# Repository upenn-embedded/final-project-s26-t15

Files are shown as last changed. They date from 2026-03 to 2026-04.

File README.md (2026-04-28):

Review Assignment Due Date (https://classroom.github.com/a/-Acvnhrq)

# Final Project

**Team Number: Team 15**

**Team Name: Argus**

| Team Member Name | Email Address |
| --- | --- |
| Seth Lee | sethlee@seas.upenn.edu |
| Jerry Zhang | jerryjz@seas.upenn.edu |
| Thomas Liu | tholiu@seas.upenn.edu  |

**GitHub Repository URL: https://github.com/upenn-embedded/final-project-s26-t15.git**

**GitHub Pages Website URL:** https://upenn-embedded.github.io/final-project-s26-t15

## Final Project Proposal

### 1. Abstract

Our final project (Argus) is a pair of augmented reality glasses that utilizes a HUD and sensor suite to collect and display movement information along with live timers that always keep the user up to date with their activities. Using a STM32 MCU and XIAO ESP32S3 processors, we can wirelessly transmit data from the glasses to our pocket. Featuring a transparent OLED for the HUD, 9-axis IMU for spatial tracking, and capacitive touch sensors, we combine portability with performance. The ESP32s will relay data wirelessly from the glasses to the STM32 in the user's pocket which serves as the compute hub.

### 2. Motivation

Argus helps bridge the gap between physical activity and real-time data accessibility without sacrificing situational awareness. While commercial AR glasses often prioritize complex media ecosystems and overlays, Argus focuses on lightweight, purpose-focused architecture that offloads heavy processing to a pocket-based STM32 to minimize weight. The sensors then provide a distraction-free, hands-free HUD for users. Instead of having to look at a watch or pull out a phone, users can find relevant telemetry in their line of sight. The emphasis on power efficiency and simplicity makes it perfect for tasks like checking the direction of travel while running or biking, where looking down could be unsafe. We hope that this project can provide a base for more advanced sensors and features.

### 3. System Block Diagram

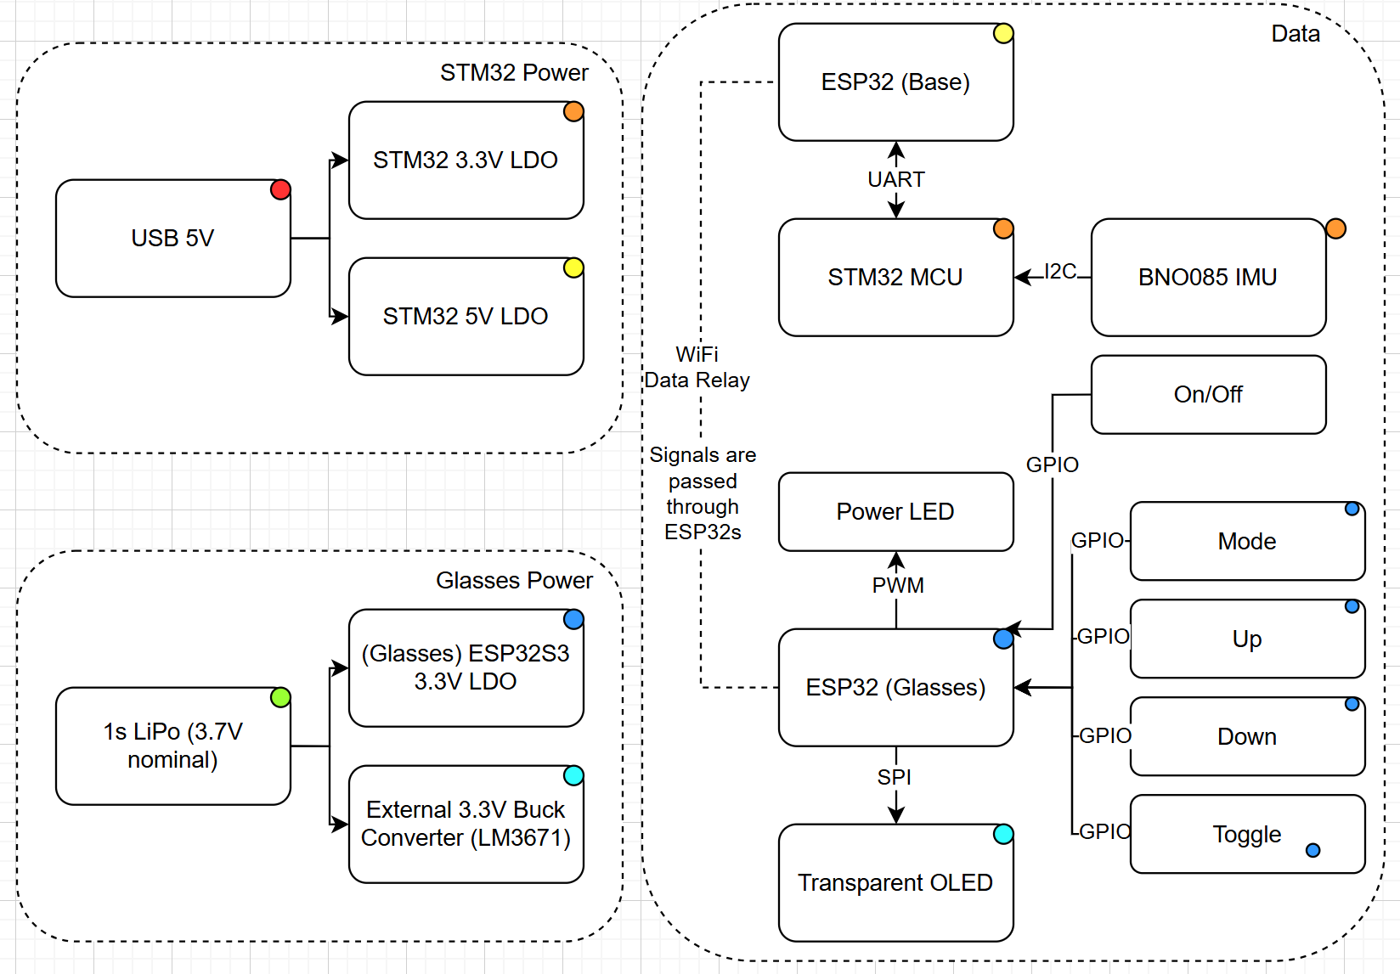
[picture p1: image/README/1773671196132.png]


### 4. Design Sketches

The frame of the glasses will be customized through 3D printing and laser cutting in order to house the hardware components.

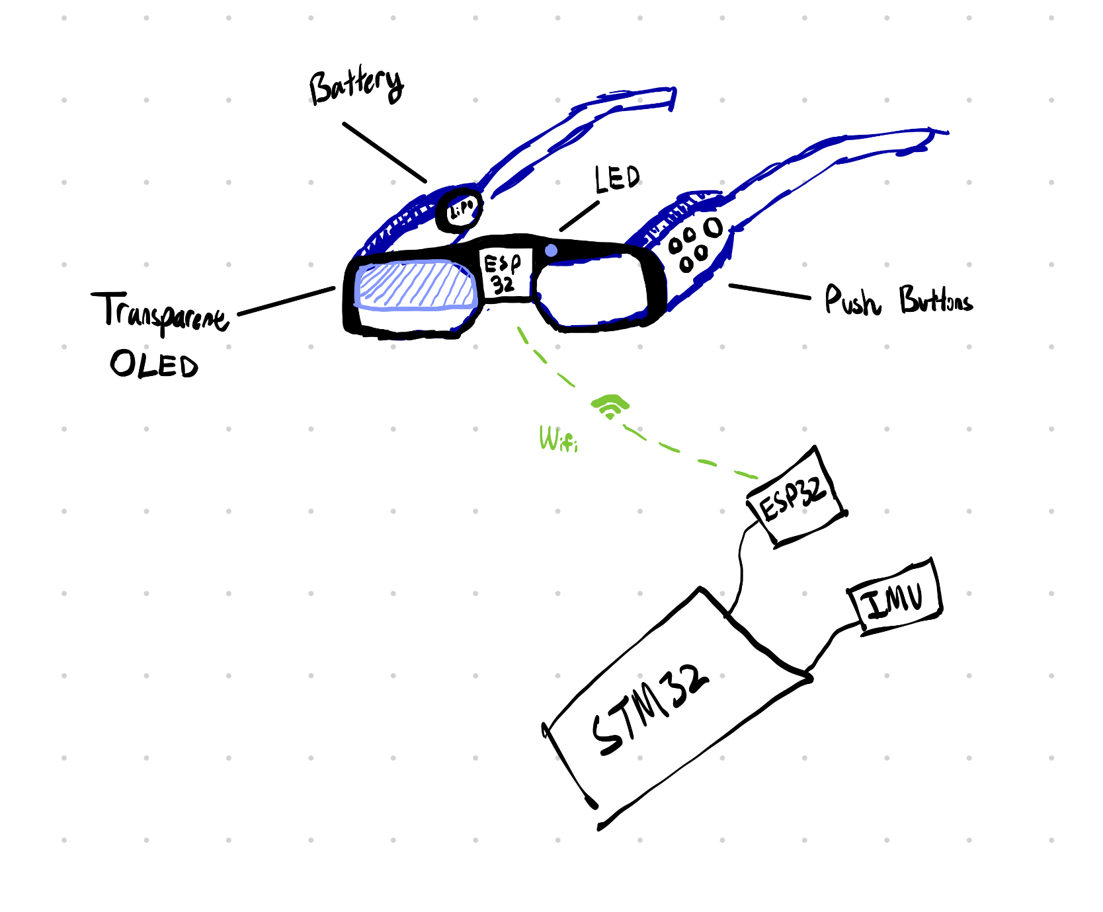
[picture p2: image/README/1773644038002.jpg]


### 5. Software Requirements Specification (SRS)

**5.1 Definitions, Abbreviations**

STM32 - STM32F411RE microcontroller on the NUCLEO-F411RE development board.

Base ESP32 - the ESP32 module connected to the STM32 via UART.

Glasses ESP32 - The ESP32 module mounted on the glasses frame. Receives data from the Base ESP32 and interacts with peripherals.

IMU - Inertial Measurement Unit. Accelerator/gyroscope sensor for step detection.

**5.2 Functionality**

| ID | Description |
| --- | --- |
| SRS-01 | The STM32 shall read the IMU accelerometer data over SPI at a minimum rate of 50 Hz to enable accurate step detection. |
| SRS-02 | The step detection algorithm shall detect a walking step within 400ms of it occuring, with no more than 10% error over a 20-step walk test. |
| SRS-03 | The display shall update its shown content within 500ms of a button press. This includes the full round-trip: glasses ESP32 → base ESP32 → STM32 → base ESP32 → glasses ESP32 → display. |
| SRS-04 | The STM32 shall synchronize its RTC with NTP time via the base ESP32 over UART once at startup. |
| SRS-05 | The display shall cycle through atleast three different modes, such as: time view, step count view, and compass view. |
| SRS-06 | The STM32 shall receive and process data from the base ESP32 over UART within 100ms of transmission. |
| SRS-07 | The STM32 shall compute the compass direction from the magnetometer data from the IMU and display cardinal direction (N, NE, E, SE, S, SW, W, NW) accurate to within +/- 22.5 degrees after calibration. |
| SRS-08 | The OLED display will communicate using SPI translated through UART wirelessly between the two ESP32S3 modules to maximize screen data bandwidth. |

### 6. Hardware Requirements Specification (HRS)

**6.1 Definitions, Abbreviations**

See Section 5.1 for all definitions and abbreviations.

**6.2 Functionality**

| ID | Description |
| --- | --- |
| HRS-01 | The system shall use an IMU with atleast 3-axis accelerometer, 3-axis gyroscope, and 3-axis magnetometer capabilities, communicating over SPI, to provide motion data for step-count and compass data for direction. |
| HRS-02 | The display shall be smaller enough to mount on glasses frames and support atleast two lines of text output. |
| HRS-03 | Several push buttons shall be mounted on the glasses frame and be able to register a press within 100ms of acutuation to enable various functionalities such as toggling modes, changing parameters, and powering on and off. |
| HRS-04 | Two ESP32 modules shall be able to maintain wireless connection with a round-trip latency of less than 500ms within 5m of distance. |
| HRS-05 | The STM32 shall communicate with the base ESP32 over UART at a baud rate of atleast 9600 bps. |
| HRS-06 | The glasses shall be powered by a battery capable of powering the glasses for atleast 15-30 minutes continuously. |

### 7. Bill of Materials (BOM)

The major components needed are as follows: Nucleo STM32 F411RE Devboard, 2x XIAO ESP32S3 modules (wifi communication), DFR0934 monochrome transparent OLED (HUD), 9-DOF IMU (motion tracking), a LED to indicate power and debug features, external buck converter to isolate OLED from possibly noisy ESP32 LDO, 5 switches (mode, up, down, toggle, on/off), and a battery.

| Component | Part Selection | Justification & Requirement Link |
| --- | --- | --- |
| Main Processor | NUCLEO-F411RE | Master Controller: Handles the step-detection algorithm (SRS-02), RTC synchronization (SRS-04), and I2C sensor polling at 50 Hz (SRS-01). Selected for its ability to use interrupts and also industry standard usage. |
| Wireless Bridge  | 2x XIAO ESP32S3 | Communication Relay: Facilitates the 500ms round-trip display update (SRS-03) and provides the wireless link required by HRS-04. Operates as a simple relay with no application code to satisfy system constraints. |
| Transparent HUD  | DFR0934 OLED | Visual Interface: Meets HRS-02 for small-form-factor mounting and supports the multi-mode display requirements (Time, Steps, Compass) outlined in SRS-05. |
| Motion Tracking  | 9-DOF IMU (BNO085)  | Navigation & Fitness: Provides the 3-axis Accel/Gyro/Mag data required by HRS-01. Enables compass accuracy within 22.5 degrees (SRS-07) and step detection (SRS-02). |
| Power Isolation  | Buck Converter | System Stability: Ensures that WiFi bursts do not cause brownouts or electrical issues, allowing the battery to meet the 15 to 30 minute continuous run-time requirement (HRS-06). |
| User Input | 5x Tactile Switches | Manual Control: Satisfies HRS-03 for registration within 100ms. Enables mode toggling (SRS-05) and system power management. |
| Power Source | 1S LiPo Battery | Portable Battery: Selected to meet the weight requirements for glasses-mounting while satisfying the run-time specifications of HRS-06. |
| Status Indicator | Power LED | Visual Feedback: Provides an immediate hardware-level On state to confirm the success of power-on sequences defined in HRS-03. |

https://docs.google.com/spreadsheets/d/1X19fjBgSUE6MPIu0bsC3vZN--DqyP1meB3pUoyBd7XM/edit?usp=sharing

### 8. Final Demo Goals

On Demo day, the smart glasses will be demonstrated by having someone wear them. The STM32 with its base ESP32 will have remain close by when the user is using the smart glasses to reduce latency and improve connectivity between the two ESP32 modules. Features will be tested by activating them using the side push buttons and moving around which will verify functionality of IMU features (cardinal direction and step counting) and the screen updating.

### 9. Sprint Planning

| Milestone  | Functionality Achieved | Distribution of Work |
| --- | --- | --- |
| Sprint #1  | 1] Get individual components to connect to each other, i.e STM32 and ESP32.<br />2] Verify UART connection between STM32 and ESP32, wifi-connection, and confirm that STM32 can recieve button press.<br />3] Begin prototyping glasses frame + begin calibrating screen for close-up view.<br />4] synchronize RTC time with NTP time via wifi. | Seth - Firmware<br />Jerry - Display + Firmware<br />Thomas - Glasses Frame |
| Sprint #2  | 1] Get STM32 to receive IMU data over I2C and display steps / compass direction<br />2] Get display to show text/time.<br />3] Finalize power source for the glasses display + ESP32.<br />4] Finalize Glasses Frame and test it for proper fitting/balance. | Seth - Firmware<br />Jerry - Display + Peripheral Integration<br />Thomas - Glasses Frame  |
| MVP Demo | 1] Get steps algorithm and compass direction working.<br />2] Fully integrate ESP32 and display onto glasses frame.<br />3] Ensure that calibration + synchronizing of RTC time work as expected. | Seth - Firmware<br />Jerry - Peripheral Integration + Calibration<br />Thomas - Integration |
| Final Demo | Ensure that final product is fully functional and meets requirements. | |

**This is the end of the Project Proposal section. The remaining sections will be filled out based on the milestone schedule.**

## Sprint Review #1

### Last week's progress

1. Finalized most of BOM and determined general design of prototype that we are now working towards.
2. Ordered parts for parts of the deisgn that we are more certain on
3. Planning design and build schedule.

### Current state of project

1. Found several issues with current design mostly surrounding difficulty of writing I2C driver with our IMU.

-> Strange behavior listed in errata of F411 where clock stretching results in miscommunication between master and slave, which is problematic since the previous IMUs chosen (BNO085 or BNO055) both use it. Also discovered these devices don't contain built in step counter and I2C will be very difficult to write.

-> Switched to LSM6DS0 because it contains step counter and works over SPI. Since screen also uses SPI, it makes it convenient so we can write one driver that is also easier to write.

2. Button presses and interacting with the STM32F411 figured out

-> Basic interrupt or GPIO functionality

3. Replaced the transparent OLED with a DFR0934 along with a different design (described below) for handling the optics. This was done because the the transparent OLED would not be visible at such a close distance.
4. Calculated object distance (d0) constraints from a target virtual image distance (d1) and magnifcation (m0) constraint.

[d0 calculator (32)](https://www.desmos.com/calculator/zhws0yhlh0)

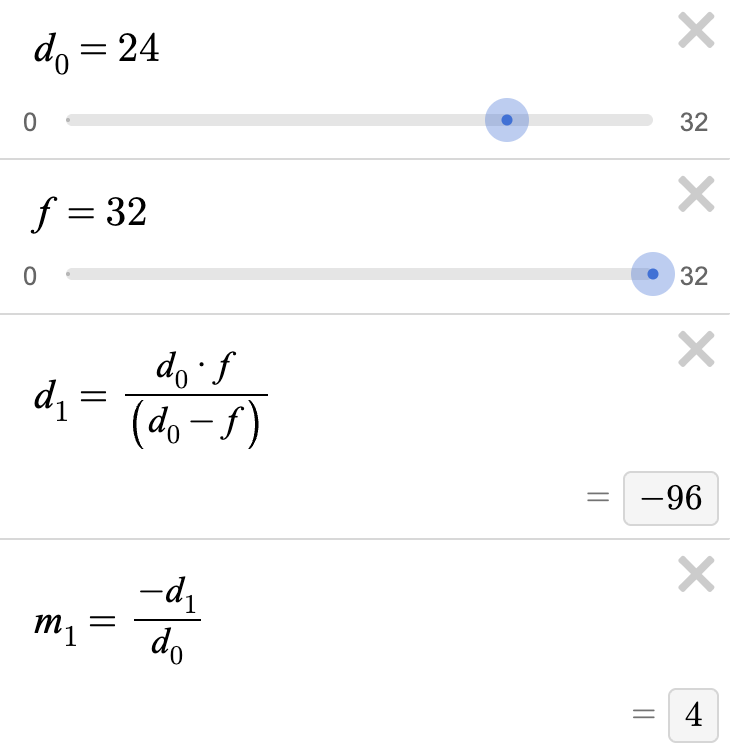
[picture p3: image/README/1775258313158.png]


4. Designed the mechanical layout for the hardware and optics Determined methods to reduce d0 due to limited focal length, and reduce mount size by adding a secondary mirror.

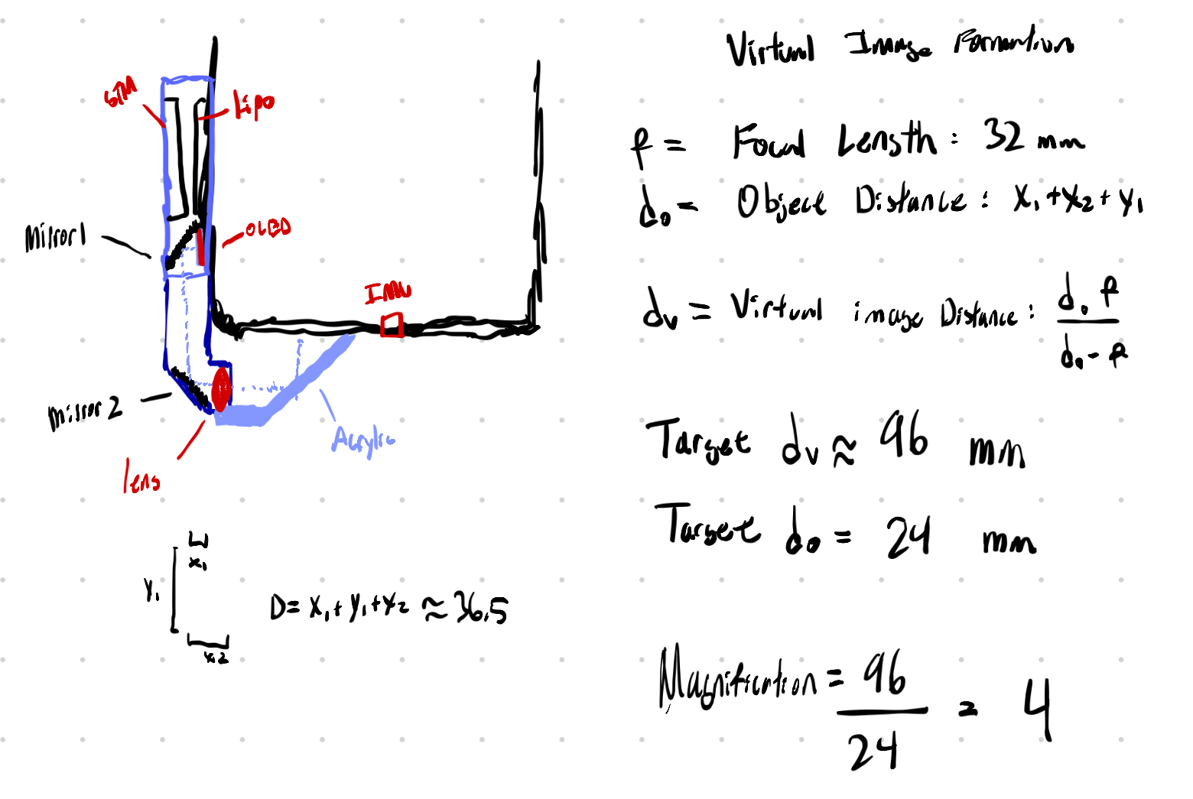
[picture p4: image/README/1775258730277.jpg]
   
5. Prototyped mounts to hold hardware so they can be clipped onto glasses.

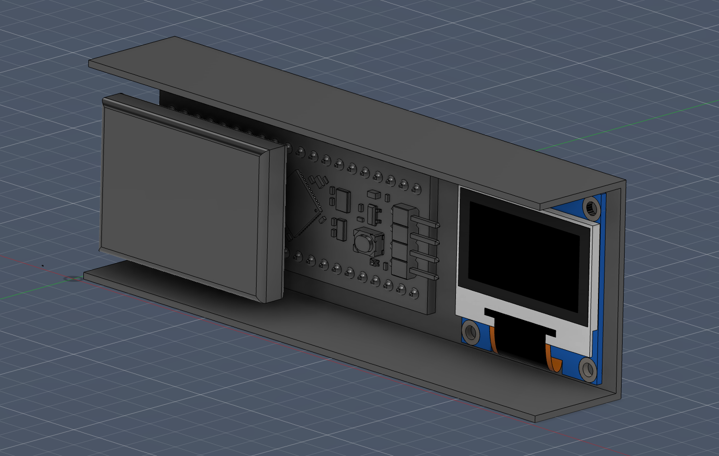
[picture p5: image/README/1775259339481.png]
   

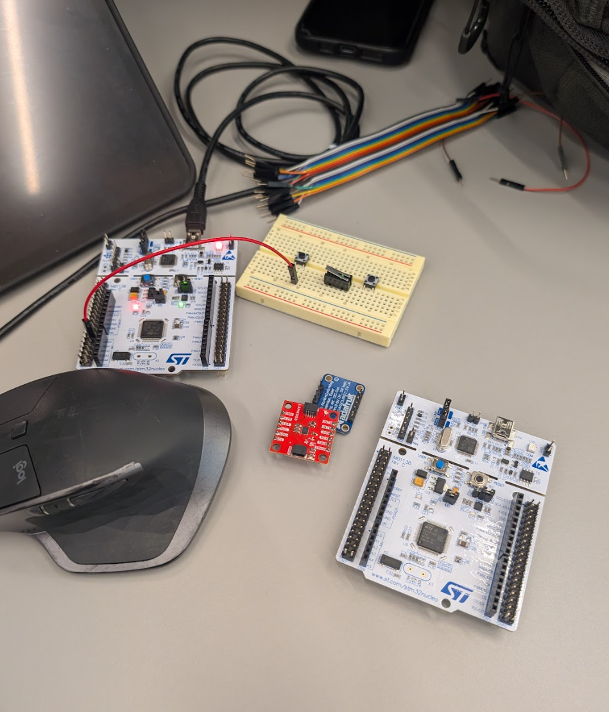
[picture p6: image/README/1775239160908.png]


### Next week's plan

1. Finish full implementation of step counter (Seth)

-> Requires full functionality of SPI drivers

-> Get it to read out onto a serial output

-> Est. time: 1hr if SPI driver is working

2. (If screen arrives) Write library and implement basic functionality of screen (Jerry)

-> Allow for some basic interfacing with screen, determine how to set the screen color or edit pixels

-> Est. time: 2-3hrs

3. Write SPI driver (Jerry)

-> SPI driver has all necessary features for at least the IMU at this time, can initialize and operate independently without excessive debugging or compatibility issues with devices

-> Est. time: 3-6hrs

4. Write IMU driver (Seth)

-> Implement all major functions (get linear movement, step tracking, etc)

-> Est. time: 3-6hrs

5. CAD and print out a prototype (Thomas)

-> 3D-print a prototype (or gather a pair of real glass) and mount a dummy weight mimicking our device onto glasses and test weight distribution.

-> Est. time: 3-6hrs

Hopefully we also get some parts in.
Work Distribution:
Seth: Firmware and development of STM32 portions
Jerry: Electrical hardware and writing SPI driver
Thomas: Mechanical design and prototyping

In case anyone is not available to work on something, everyone is reading the STM32 textbook and is proficient in mechanical design so we can assist each other if extra work is needed.

## April 9th, 2026

As of now, the main SPI driver is written and the IMU driver is in progress. Using the textbook as a reference, we're trying to write the driver for the LSM6DS0 so that it can use SPI properly. The mechanical design is nearly done (insert screenshot). We are also able to register basic GPIO input and some input capture using buttons so far on the STM32.

## Sprint Review #2

### Last week's hardware progress

This week, we targeted integrating various sensors and drivers, making sure that our devices are taking and outputting the proper data. Additionally, we hoped to get some of the new parts (OLED, lenses, Adafruit Blackpill STM32) so that we could move to our intended hardware setup. While the lenses and Blackpill STM32 have not arrived, the OLED has arrived.

After analyzing the hardware components' sizes and the constrains on the optical components, new designs analyzed. The final design for prototyping will resemble design one, but with the hardware shifted to account for proper lens spacing. Later, prototypes will look like design three if space is too constrained.

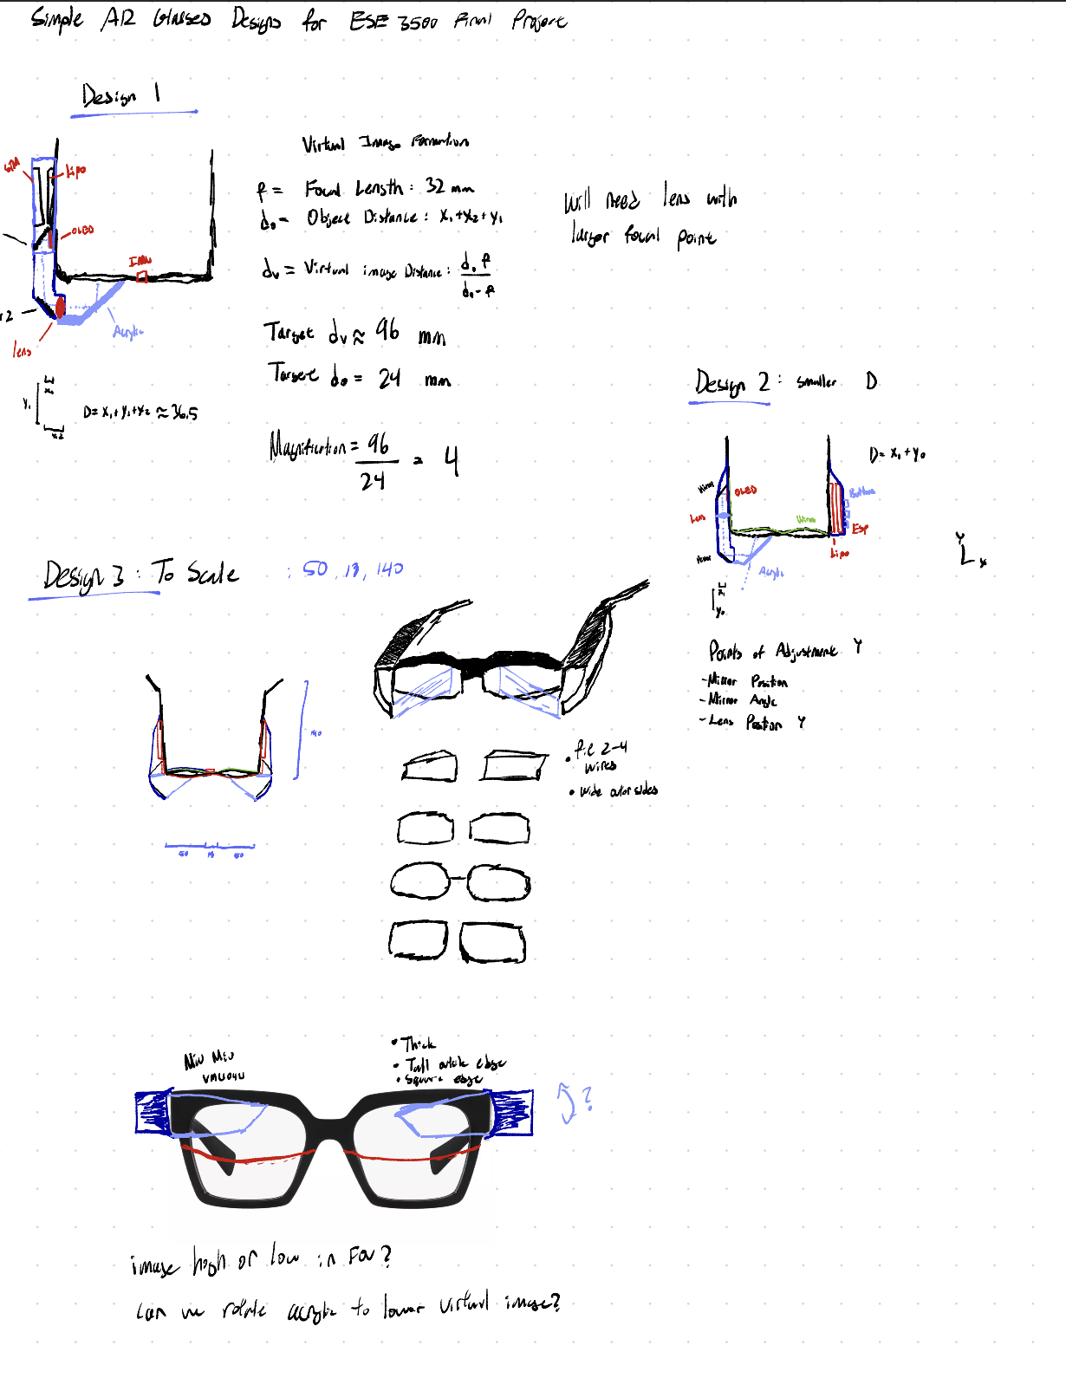
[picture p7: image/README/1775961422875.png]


To attempt to reduce the total thickness of the mounts, the furthest distance between the mirror and the OLED was minimized. Onshape was used to simulate raytracing by creating variables and minimizing the base length through different configurations.
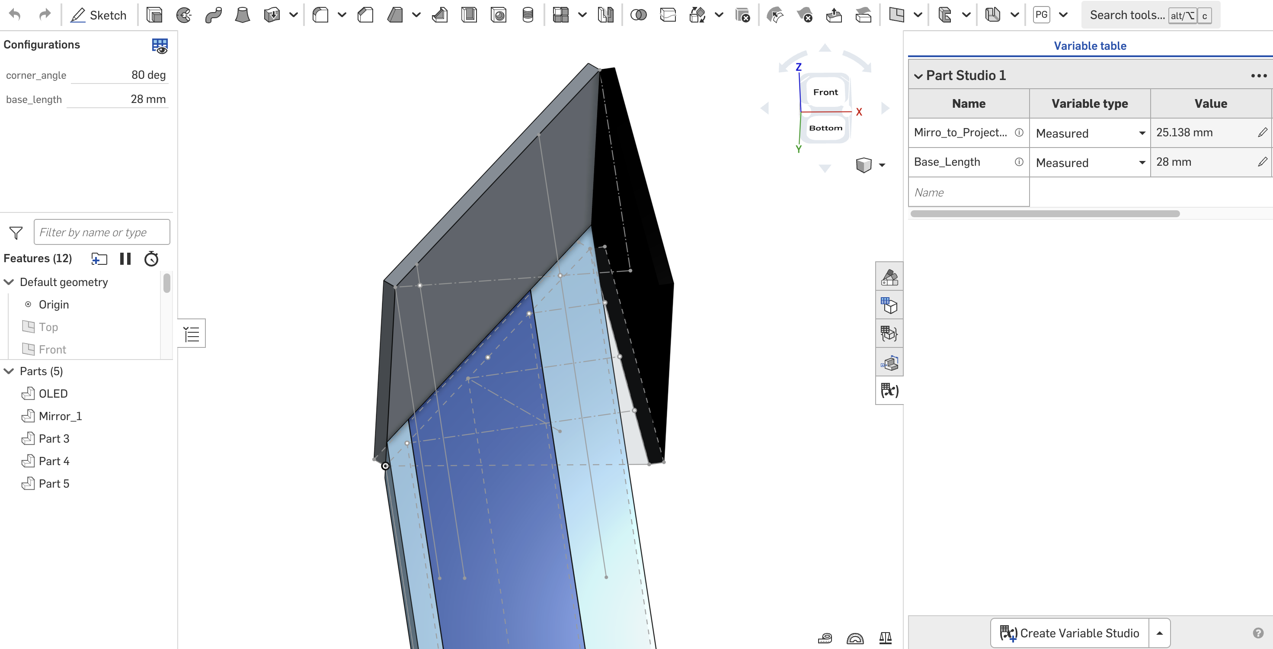
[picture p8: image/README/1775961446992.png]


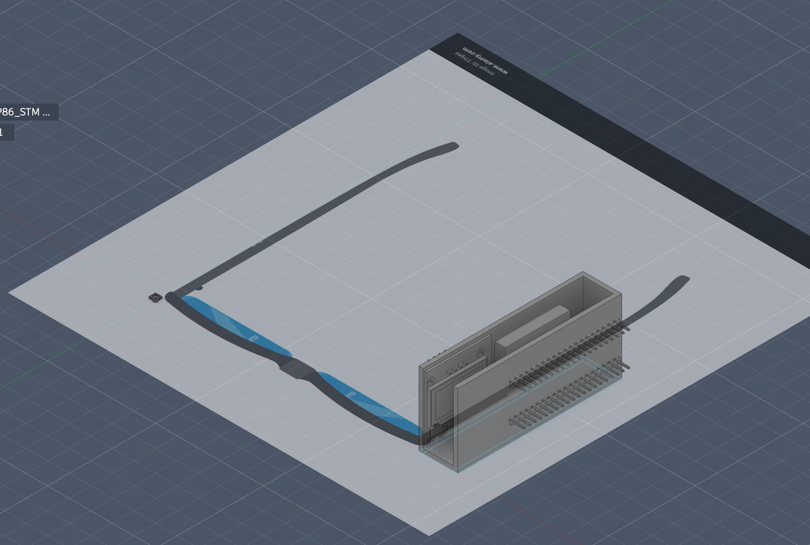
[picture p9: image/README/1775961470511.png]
Once the hardware arrived, components were measured with calipers to verify their measurements. A pair or glasses was also measured as a reference. Then, a canvas scaled to the glasses' size was imported into Fusion 360, where components were resized and the mount was scaled. Printing is underway to enable testing of the optics once the mirrors and lens arrives.

### Last week's electrical progress

Last week, we made some important progress on the integration of sensors and development of the blueprint of the device. Using the basic plan we had devised last week to primarily work on device drivers, communication protocols, and developing the optical system, we have reached a position where we are satisfied with current progress and are on track to create a MVP.

The table below reiterates some of our barebones MVP guidelines:

| MVP Goal | Description | Status |
| --- | --- | --- |
| #1. IMU Step Counter | The smartglasses will contain basic motion tracking capabilities, using an IMU to track the wearer's steps. | Complete. The SPI and IMU drivers have been fully written for the LSM6DS0, but there are other issues (written below). |
| #2. On-Screen Timer System | A wearer will be able to set and be notified of timers for use such as in timing activities like cooking or taking a practice exam. | Incomplete. The timer system will be created through the use of hardware timers, the software has not been written yet. |
| #3. 2-4 Buttons for Screen Control | The smartglasses will have several buttons to interface with the GUI to interact with features such as the step counter, timer system, or compass. | Incomplete. Basic GPIO features have been tested, but software must be written. This will be complete after all other subsystems are operable. |
| #4. Optical Waveguide HUD | The smartglasses will contain an optical waveguide to translate the light of the OLED to a beamsplitter which will reflect the light into the wearer's eyes, giving the illusion of a "floating" HUD in their vision. | In Progress. The OLED has arrived and its drivers are currently being developed. The calculations for the lens size and mirrors have also been completed. |
| #5. CAD of Glasses or Waveguide Holder | The smartglasses will exist in the form of either a clip-on attachment to an existing pair of glasses or as a standalone frame. | In Progress. The CAD has partially been completed with some additional testing and printing of the parts needed. Additionally, not all of the optical hardware (mirrors) has arrived yet. |
| #6. Navigation System | The smartglasses will contain a basic navigation system consisting of a cardinal compass to allow the user to receive navigation data. This may extend outwards into the usage of GPS or other features. | The initial IMU used (LSM6DS0) does not contain the magnetometer required for the compass. A version with the magnetometer has been ordered. |

### Current state of project

To summarize, we have written drivers and tested functionality for the IMU step counter subsystem. The video below shows (poorly) the operation of the step counter:

https://drive.google.com/file/d/1mDCpxerKAkAiZ3uGaSlx3KKA8HsJcfL3/view?usp=sharing

This link will be updated to a YT video in the future.

We found that the step counter works well, although there is a delay in counting steps. This is by design as to avoid overcounting steps as a result of other oscillatory motion.

The SPI and IMU drivers were also written, taking about the expected amount of time as listed in Sprint Review #1. Unforunately, the OLED did not arrive until recently, so that was not able to be tested yet. However, the driver for that is in progress. Since it also uses SPI, we expect setup to be easier along with our past lab experience in writing a portion of a screen driver.

Here is the step counter:

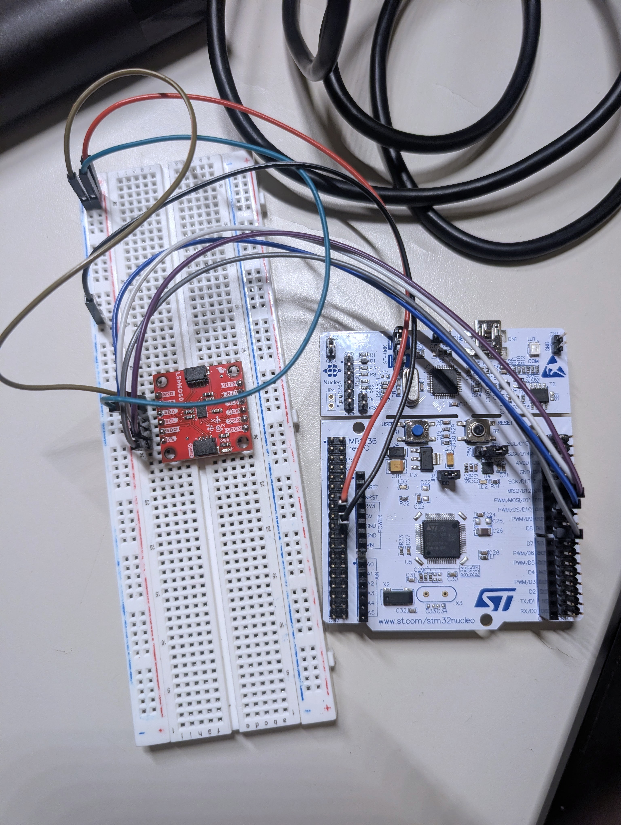
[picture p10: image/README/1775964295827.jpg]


This image shows some of our commits since the last sprint review.

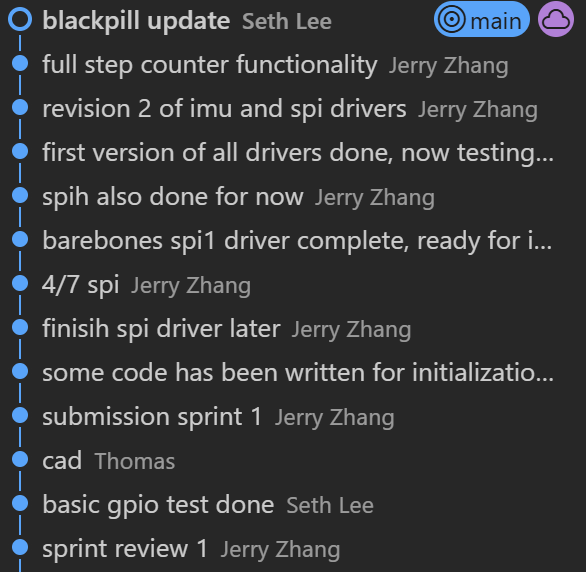
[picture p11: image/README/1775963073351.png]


Unfortunately, we reailzed that the existing parts list was inaccurate and we were unable to find certain parts, forcing us to place some orders later than we wanted to. For one, we wanted to use a 9-DOF IMU so that we could also take advantage of the magnetometer to create a compass. However, Detkin does not stock any dedicated magnetometers and their supply of IMUs is inaccurate to their parts list, only having the LSM6DS0 and some other IMUs which did not have features which we required. This led us to order the Adafruit LSM9DS1, which is effectively the same IMU (saves us time writing the driver) with a magnetometer.

The initial lens choice also proved more difficult to work with than initially thought. Due to the short focal length of the lens (32mm), we found it difficult to place all of our components within that space. However, we found a workaround where we were able to place the lens closer to mitigate this issue.

The battery has also arrived and we are considering using power management to properly adjust the 3.0 - 4.2V LiPo to the proper operating voltages so that we can use it for the entirety of its battery voltage range.

### Next week's plan

The table below illustrates our plans for the following week. To summarize, we hope to test functionality of the OLED, develop a functional CAD and 3d-printed MVP of the device, and develop the UI and user optical system.

| Goal | Owner  | Est. Time |
| --- | --- | --- |
| Develop OLED drivers, write screen functions | Seth | 4-6 Hrs |
| Implement components of UI and improve upon IMU functionality by adding compass and optimizing step counter | Jerry  | 3-4 Hrs |
| Finish CAD and optical system design | Thomas | 3-4 Hrs |
| Update SPI drivers to account for OLED | Jerry  | 1 Hr |
| Write software to handle display switching and update main loop | Seth | 2-3 Hrs |
| 3D print CAD designs and build first MVP (if parts all arrive) | Thomas | 2-3 Hrs |

In general, the goal is to prepare for the MVP demo and to develop a usable hardware system that is modular and lightweight. The OLED drivers will be written and some basic functionality involving GPIO and switching screens should also be implemented as well.

We are well on track and keeping each other up to date with progress.

## MVP Demo

**Refined System Diagram (MVP Demo & Final Diagram):**

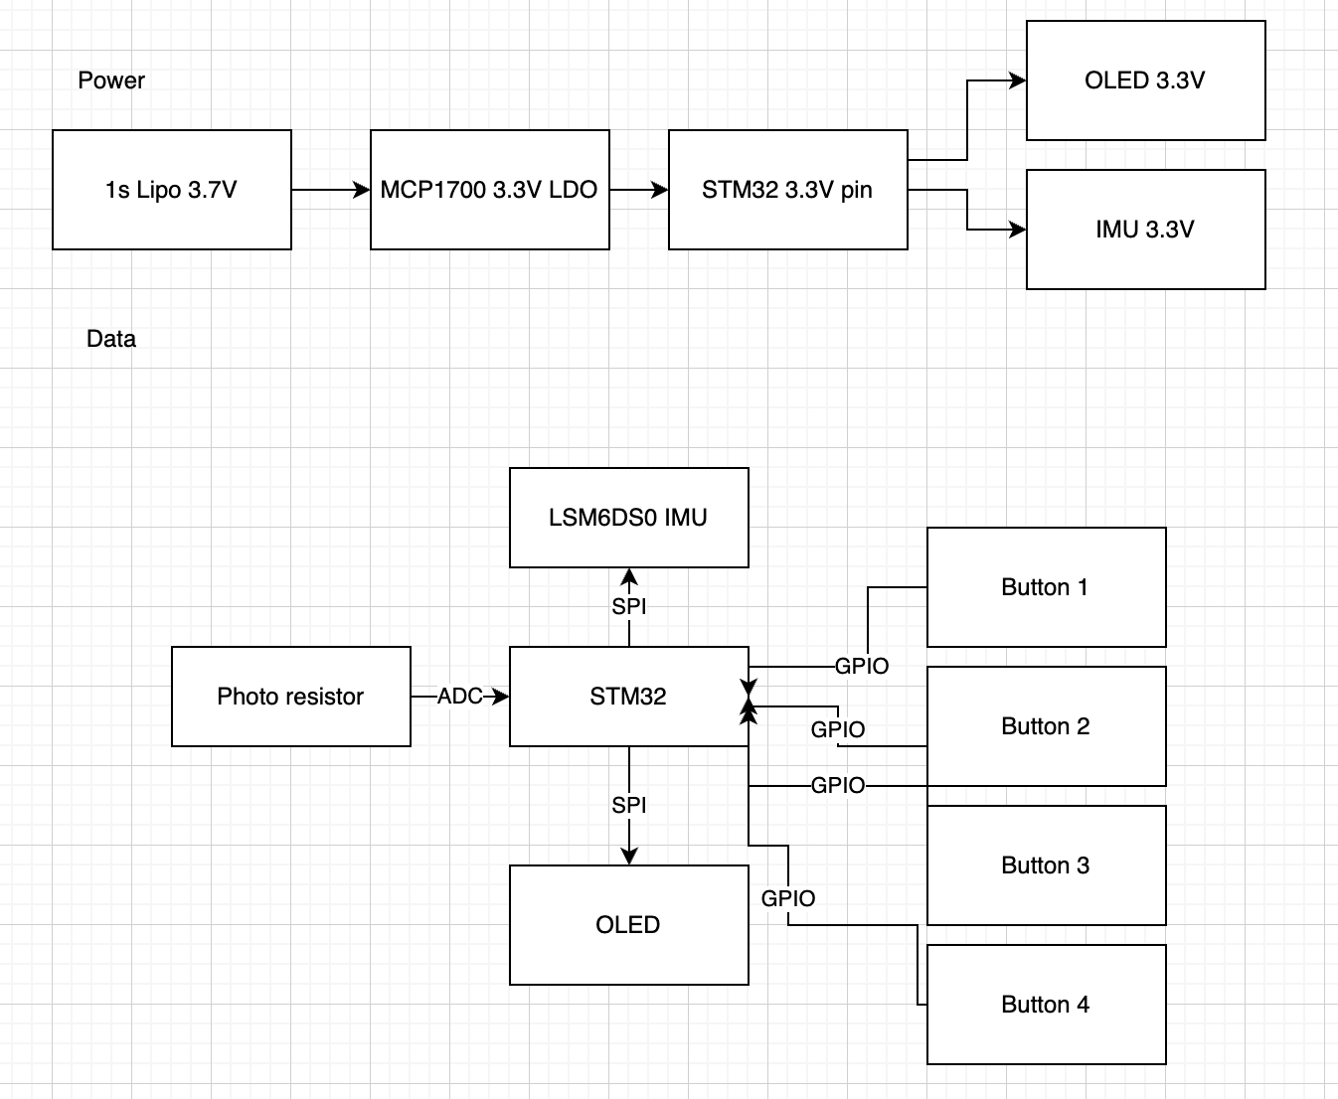
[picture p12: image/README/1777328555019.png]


Note: this diagram only shows 4 buttons instead of 5 since the fifth button on the final product was used to replace a non-functional button due to one of the GPIO pins breaking.

**Firmware Impementation:**

The main firmware is in the main.c file, which calls functions from every other .c file, including the oled.c, spi.c, imu.c, files. The main.c file is where the state of the screen is handled and where all the initialize functions are called. Then, in oled.c, spi.c, and imu.c (which are our drivers), we have the actual function code that instantiates SPI, which is used for both the OLED screen and IMU.

More specifically:

In spi.c: we have two independent SPI buses that run. One SPI bus is for the OLED screen and the other one is for the IMU.

In imu.c: we have functions that read the register from the IMU that stores the number of steps taken. This file also handles interrupts that come from the IMU, which refresh the OLED screen to display the updated step count.

In oled.c: This is the main driver for our SSD1308 oled screen. This has functions for OLED brightness, resetting the OLED screen, and drawing pixels on the OLED screen.

In font.c: This file has various draw functions that use the draw_pixel function from oled.c.

Below is an Image of the working OLED. The text on the OLED will eventually be cast to the front of the lens on the AR glasses.

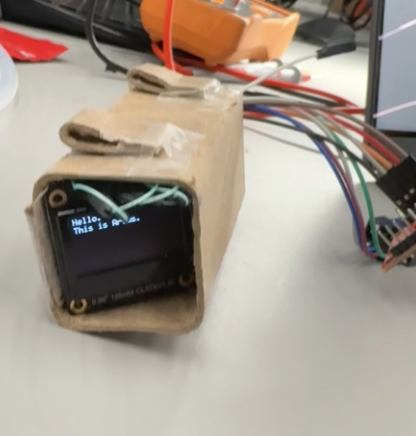
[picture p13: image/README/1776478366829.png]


**Software Impementation:**

We have achieved some of our Software Requirements. Specifically, we have satisfied SRS-01, which is to read the IMU accelerometer data for accurate step detection. Originally, we wanted to have this refresh at 50 Hz. However, this was not possible due to the slow nature of the IMU register updating. However, this is not a big deal since we’re still accurately getting step count.

We also have satisfied SRS-02 (accurate step-count).

We decided to not use the ESP-32 due to extra unnecessary complexity. Therefore, SRS-03 and SRS-04 and SRS-06 are no longer relevant.

SRS-05 is partially completed since we have the basic functionality of cycling between various screens. However, we do not have the magnetometer setup yet (SRS-07), so we are still working on that.

For SRS-08, the OLED works through SPI. However, we decided not to use the ESP32 so the ESP32 part of the requirement is irrelevant. The OLED is fully functional, however.

Below is a picture of the IMU setup.

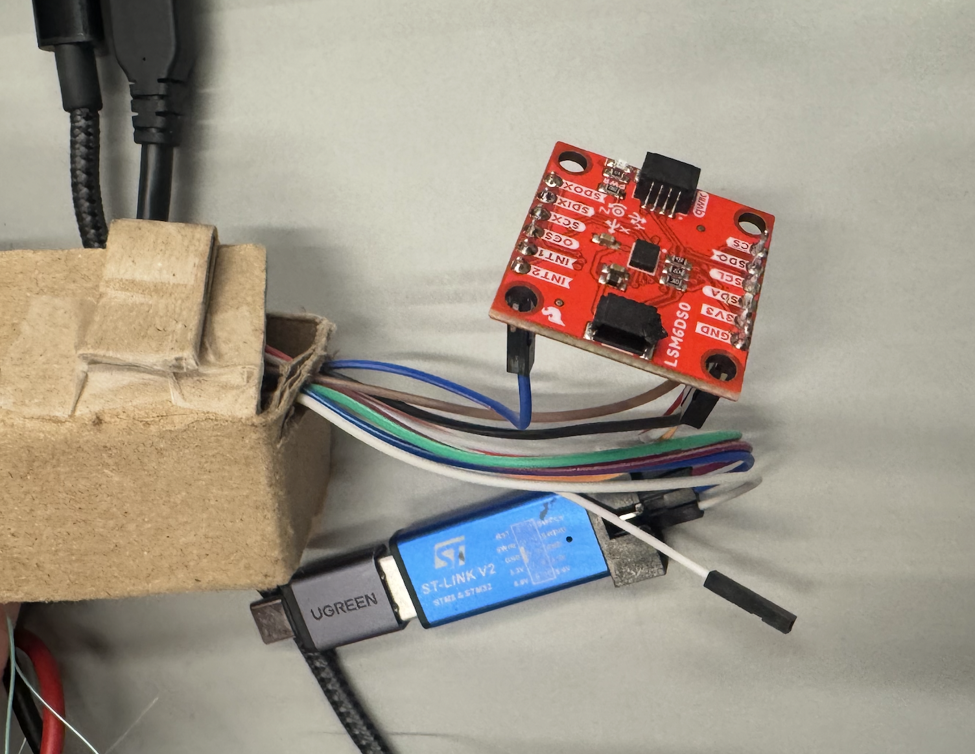
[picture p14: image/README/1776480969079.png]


**Hardware Implementation:**

For HRS-01: we are partially done with this hardware requirement except we currently are using a 6-axis accelerometer because the 9-axis accelerometer we bought requires using I2C, which we do not have setup yet.

For HRS-02: we have satisfied this since our OLED fits on the glasses frame extension and also can display more than 2 lines of text.

For HRS-03: several push buttons register within 100ms and do various functions, such as changing what is on the OLED display.

For HRS-04/HRS-05: Not relevant because we aren’t using ESP32.

For HRS-06: We have not tested battery life yet. However, eliminating the use of the ESP32 saves a lot of power since the OLED and STM32 alone are relatively power efficient and not too power hungry.

**Other Project Elements:**

The lens drives many dimensions of the container that encloses the components. Because it has not arrived yet, we decided to create a simple, flexible chasis using thin, single layer cardboard. Based off of the measurements validated with a caliper, and the latest design, a cardboard cutout was made.

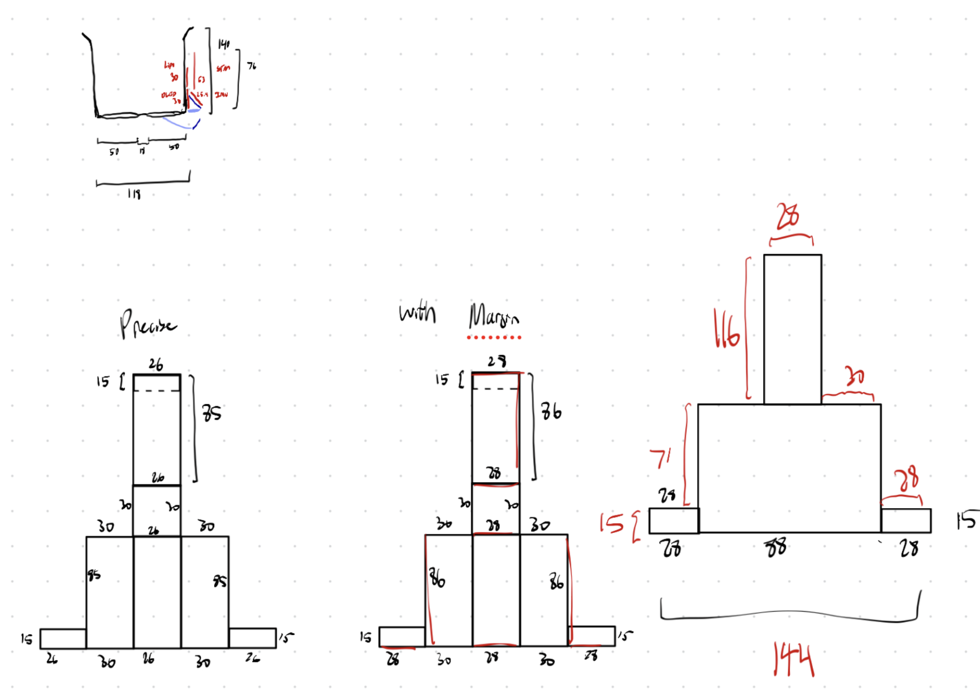
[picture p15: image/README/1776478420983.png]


The components were then housed inside the cardboard cutout, proving that they could be connected and fit into these dimensions. The buttons were also placed and connected internally.

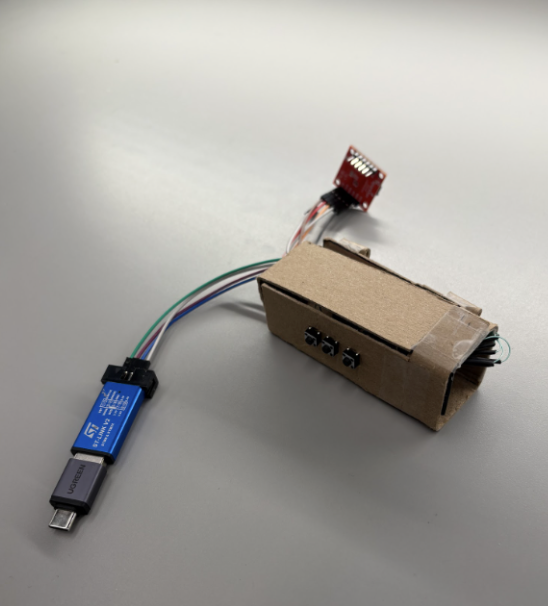
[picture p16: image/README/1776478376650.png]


To enable connection to a pair of glasses, slots were added onto the side of the enclosure. During testing, it was found that the orientation of teh enclosure deviated form expected due to the weight of the hardware. A solution was developed for the CAD where the frame of the glasses would be built into the enclosure rather than using a detachable design.

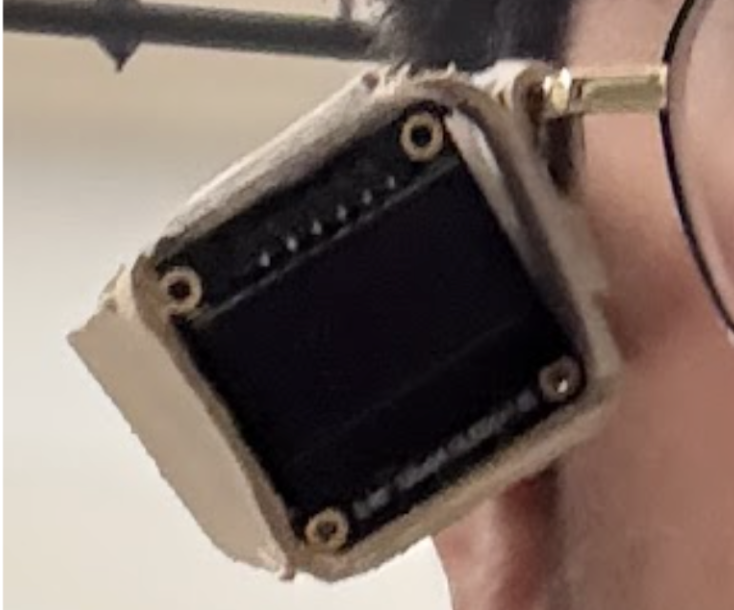
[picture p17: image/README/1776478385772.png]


The CAD was also updated with the new dimensions of the mirror.

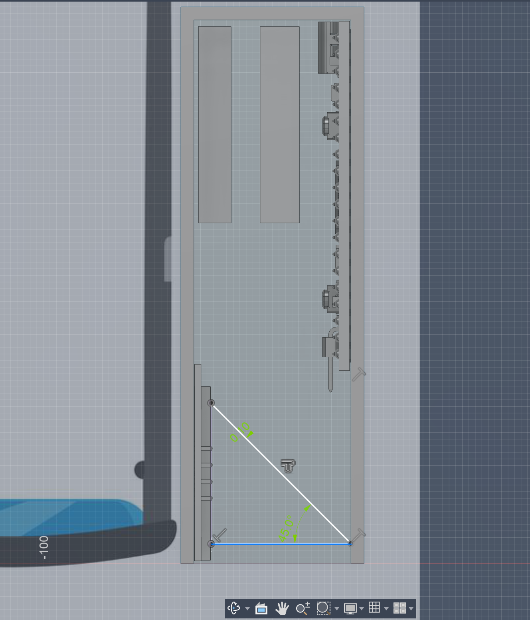
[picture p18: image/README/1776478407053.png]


**Risks:**

Due to the lens not arriving yet, the optical design could not be validated. To ensure no major design changes were needed, we conducted an analysis of the design from an optical standpoint, verifying that the virtual image could be created with our latest dimensions and components.

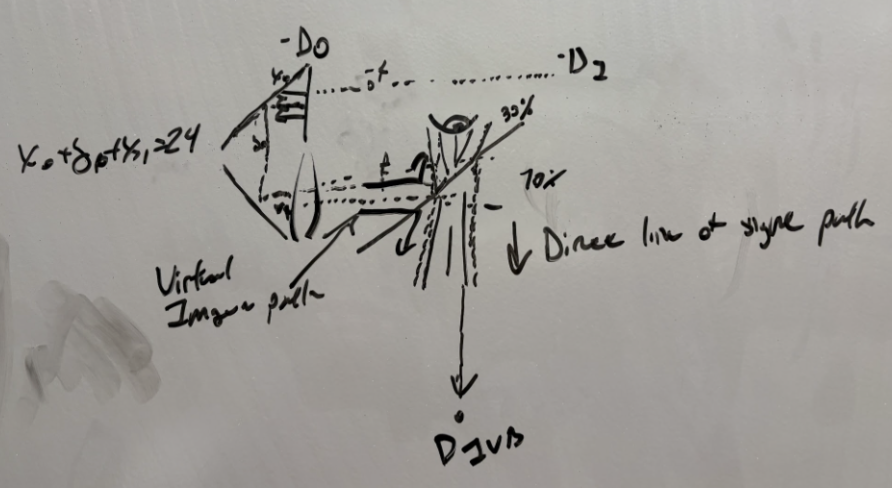
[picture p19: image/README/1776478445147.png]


We also verified by analyzing the rays in an optics simulation, verifiying that our new lens and beamsplitter would create the expected image.

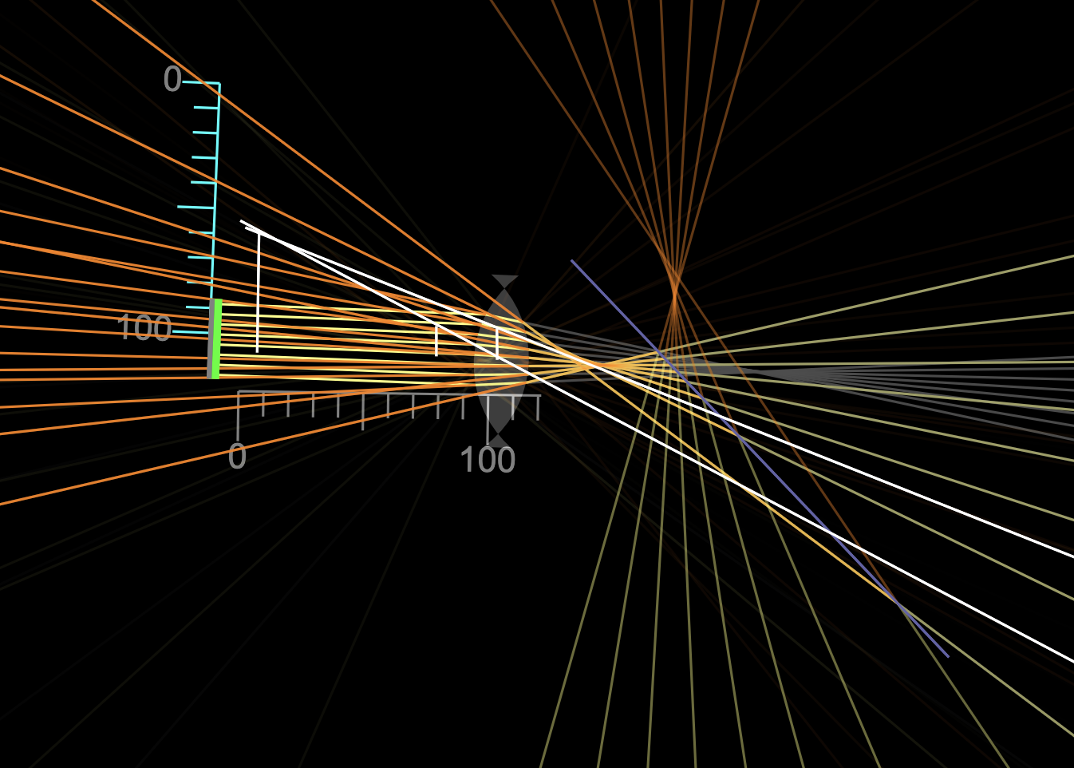
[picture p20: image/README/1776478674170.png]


## Final Updates

A new lens was ordered due to supply chain delays with the original lens. The new lens is a 25mm diameter lens with a focal point of 71mm. Initially, the object distance remained the same as before, creating a new image distance and magnification. However, a new constraint was discovered: the human eye focuses best at distances greater than 25cm. Thus, the object (the OLED) must be moved so that the virtual image is at an absolute distance of greater than 250mm. Using the equations for a virtual image, a new object distance of 56mm was chosen. Thus, the encolosure had to be redesigned to account for this.

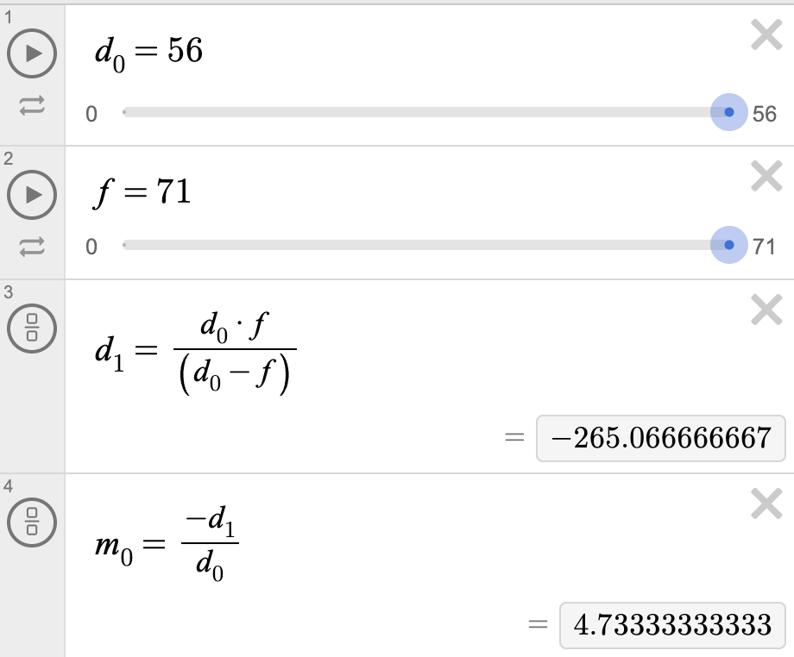
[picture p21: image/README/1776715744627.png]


While adjusting the CAD, it became apparent that the placement and orientation of the mirrors affected the object distance, or the distance traveled by the light before reaching the lens. To account for light emmited from all edges of the lens, the mirrors must be placed parallel to each other so that the horiontal distance remains constant.

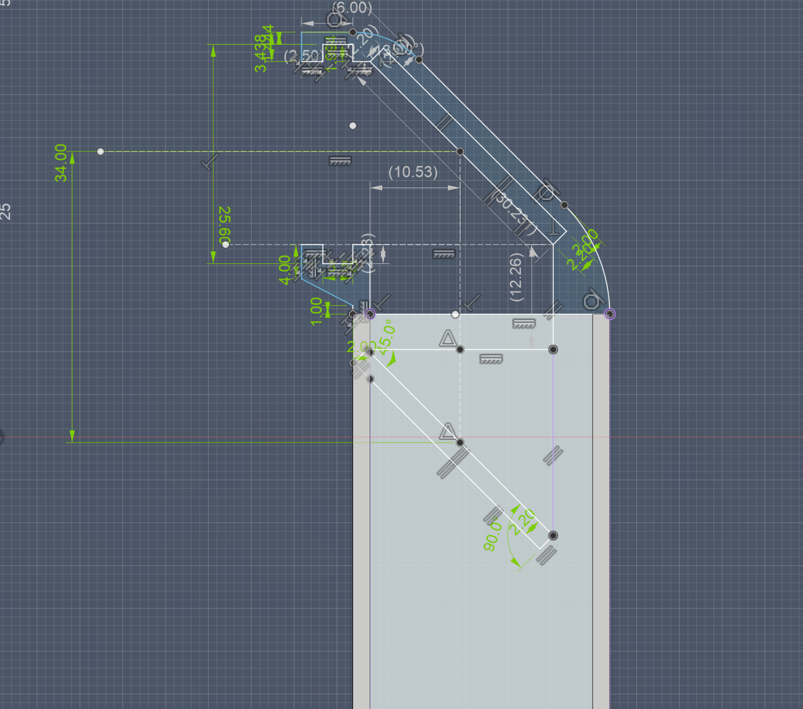
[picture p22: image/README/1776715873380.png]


Finally, the enclosure could be printed.

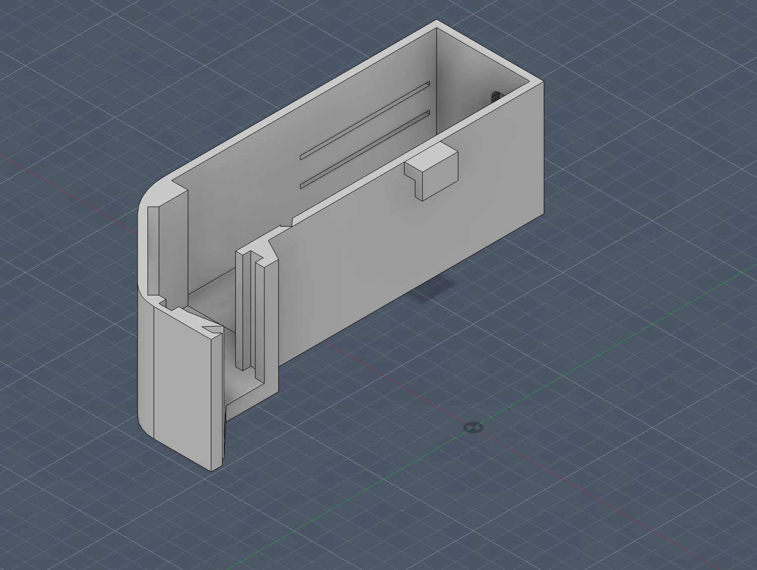
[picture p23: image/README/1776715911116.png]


Assembly of hardware components began:

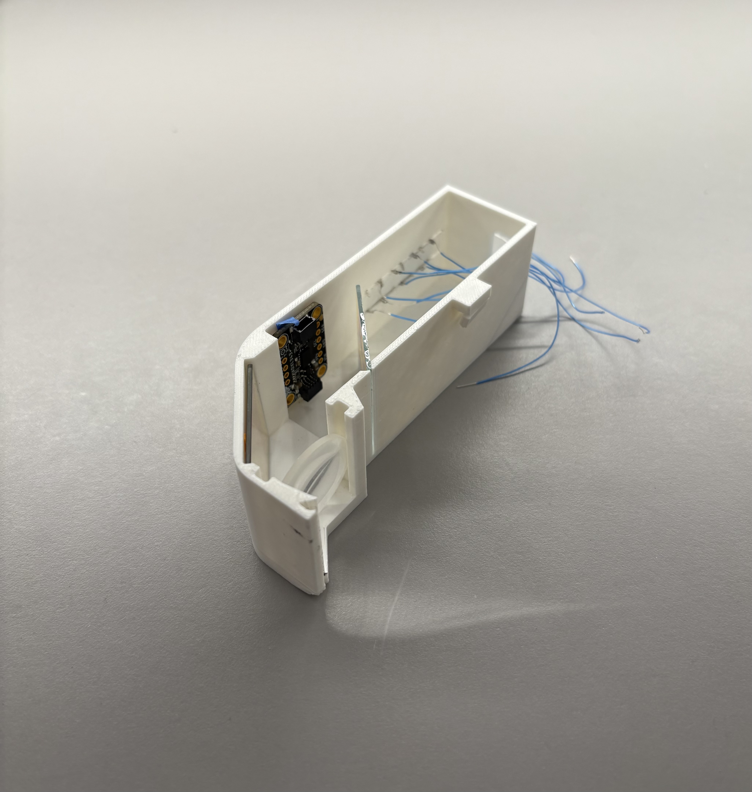
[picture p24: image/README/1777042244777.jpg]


Testing of the projection:
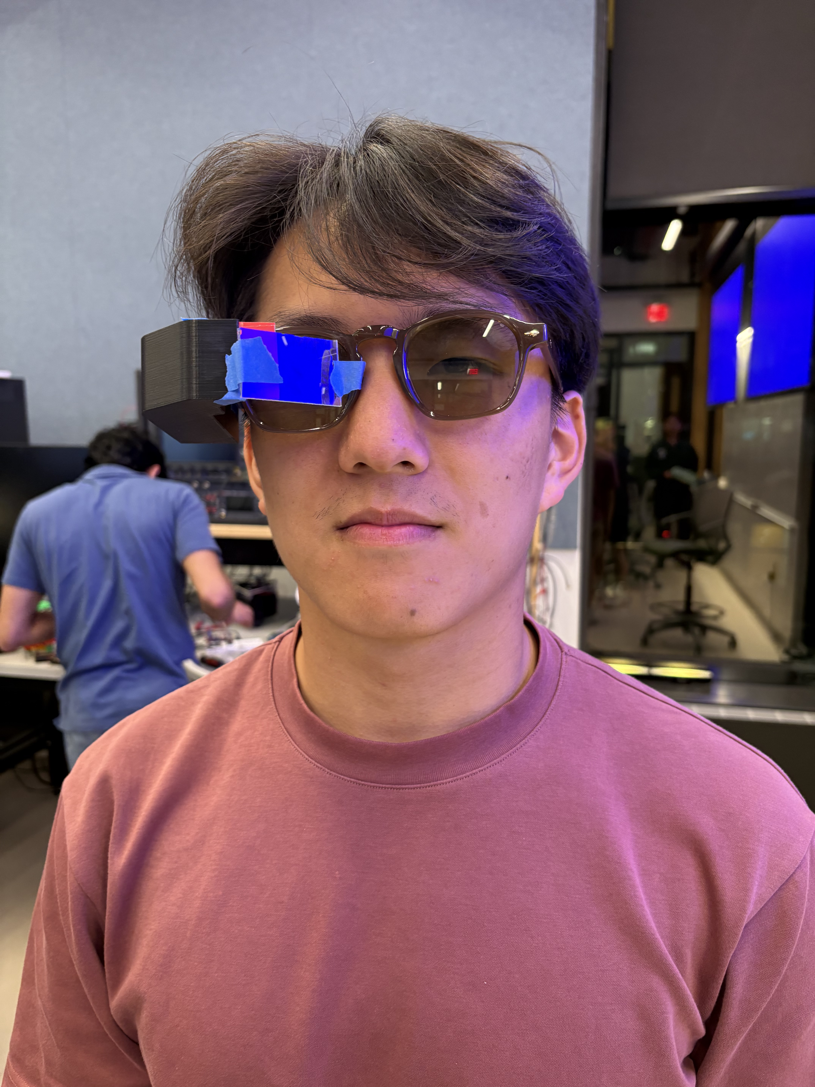
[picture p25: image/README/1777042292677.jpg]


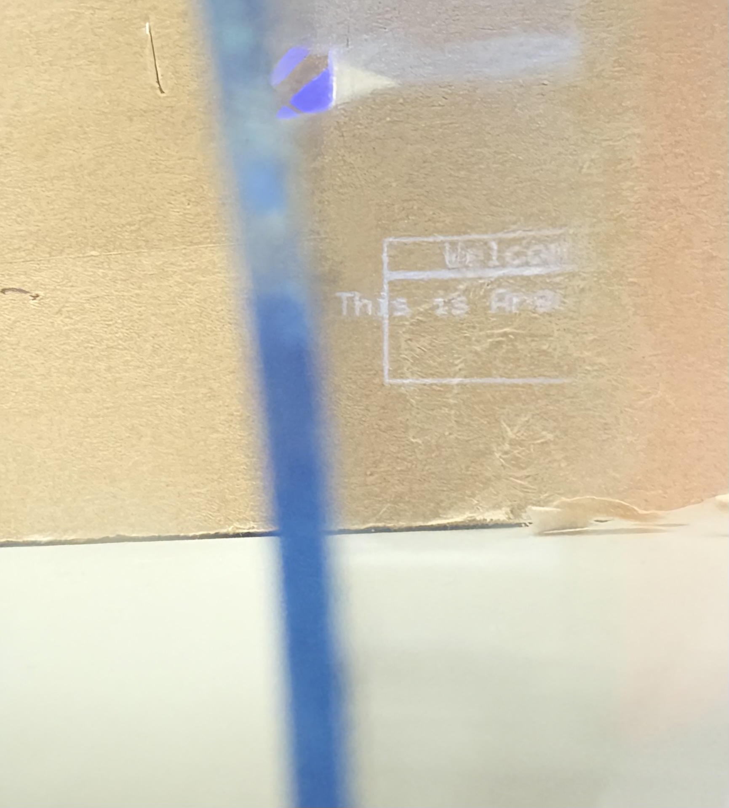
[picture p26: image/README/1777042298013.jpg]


## Final Report

Don't forget to make the GitHub pages public website!
If you’ve never made a GitHub pages website before, you can follow this webpage (though, substitute your final project repository for the GitHub username one in the quickstart guide):  [https://docs.github.com/en/pages/quickstart](https://docs.github.com/en/pages/quickstart)

### 1. Video

Link: https://drive.google.com/file/d/1iFLSCSgxxamlYA9-O-7qOhsk4T2GP4I9/view?usp=sharing

### 2. Images

Demo Day Success:

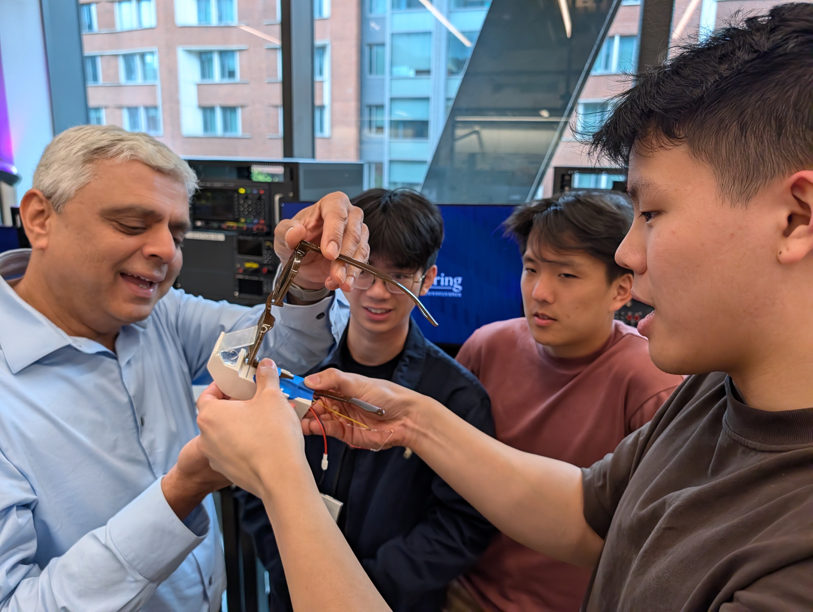
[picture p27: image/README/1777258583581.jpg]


Final Assembly:

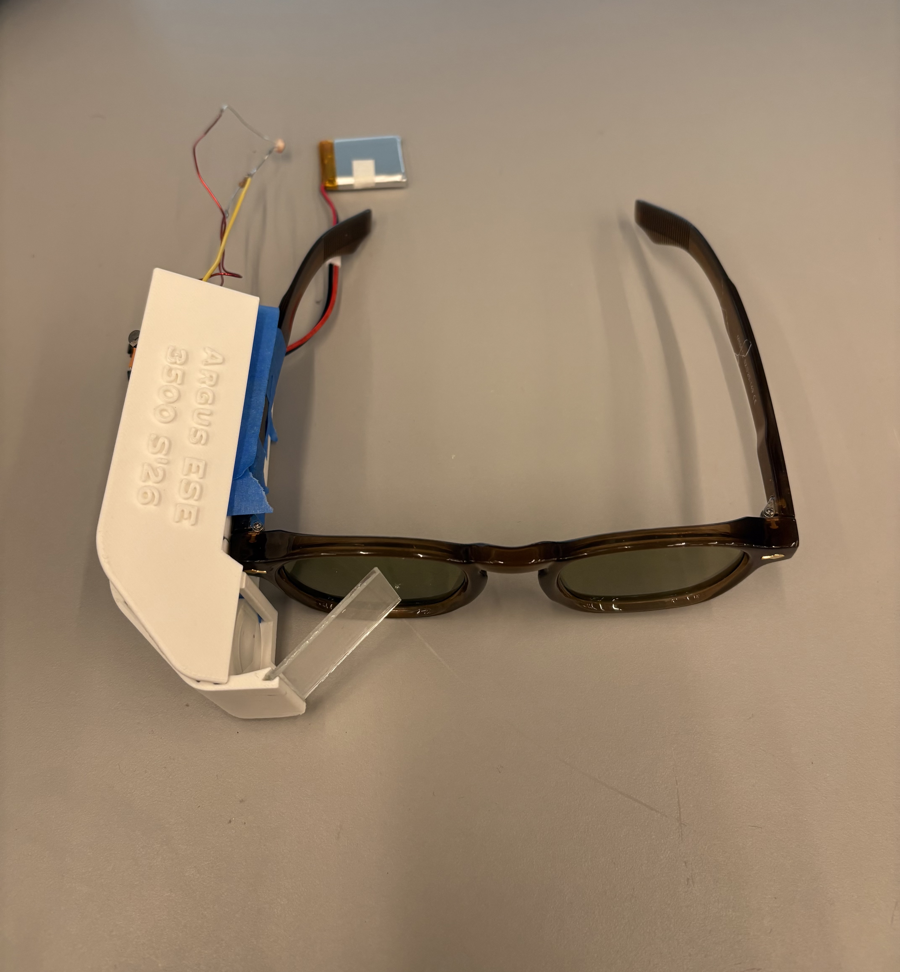
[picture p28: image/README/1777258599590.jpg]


Visible Projection:

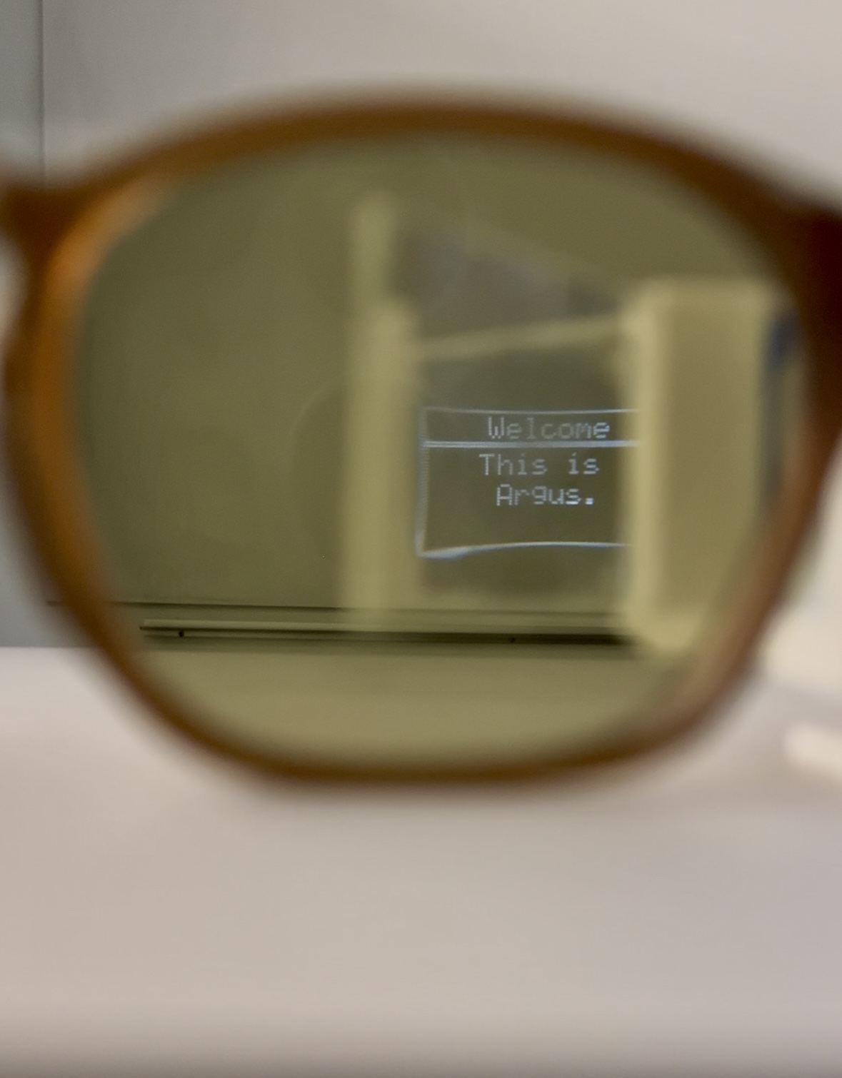
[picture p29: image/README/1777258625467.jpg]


Final CAD:

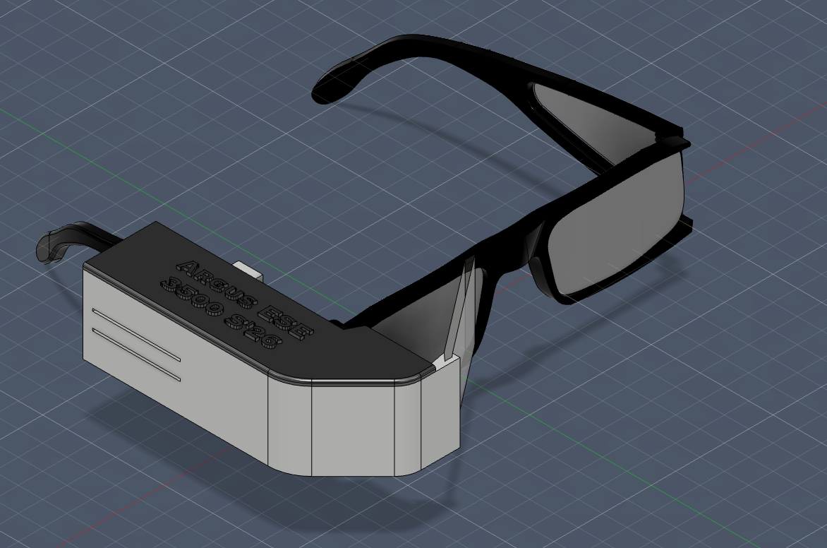
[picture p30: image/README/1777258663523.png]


Electrical Systems:
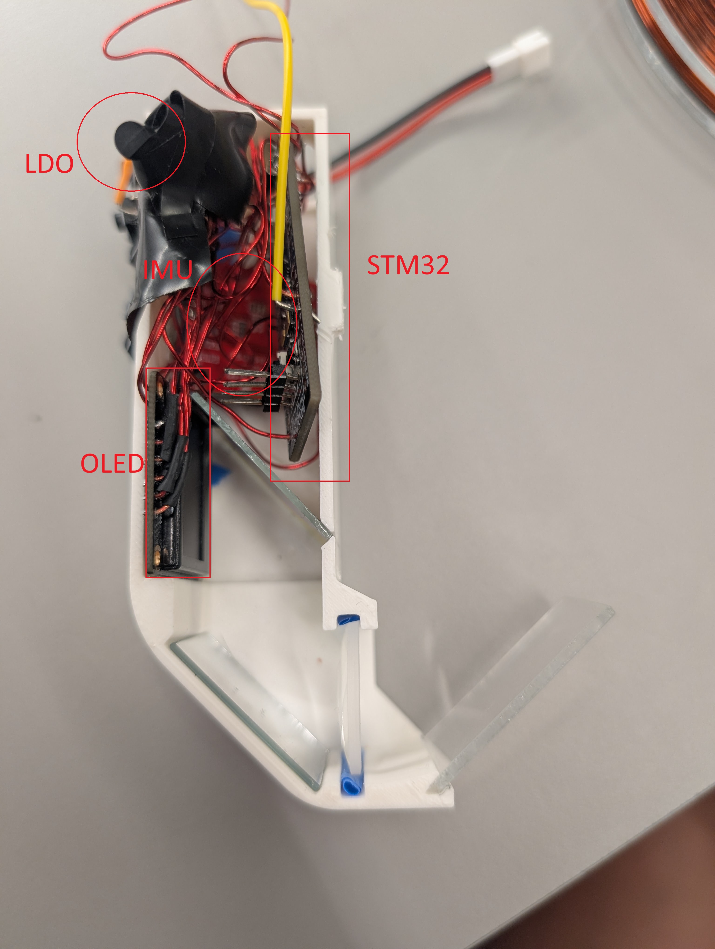
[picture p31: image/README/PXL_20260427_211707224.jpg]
Electrical Systems


Firmware and Drivers:
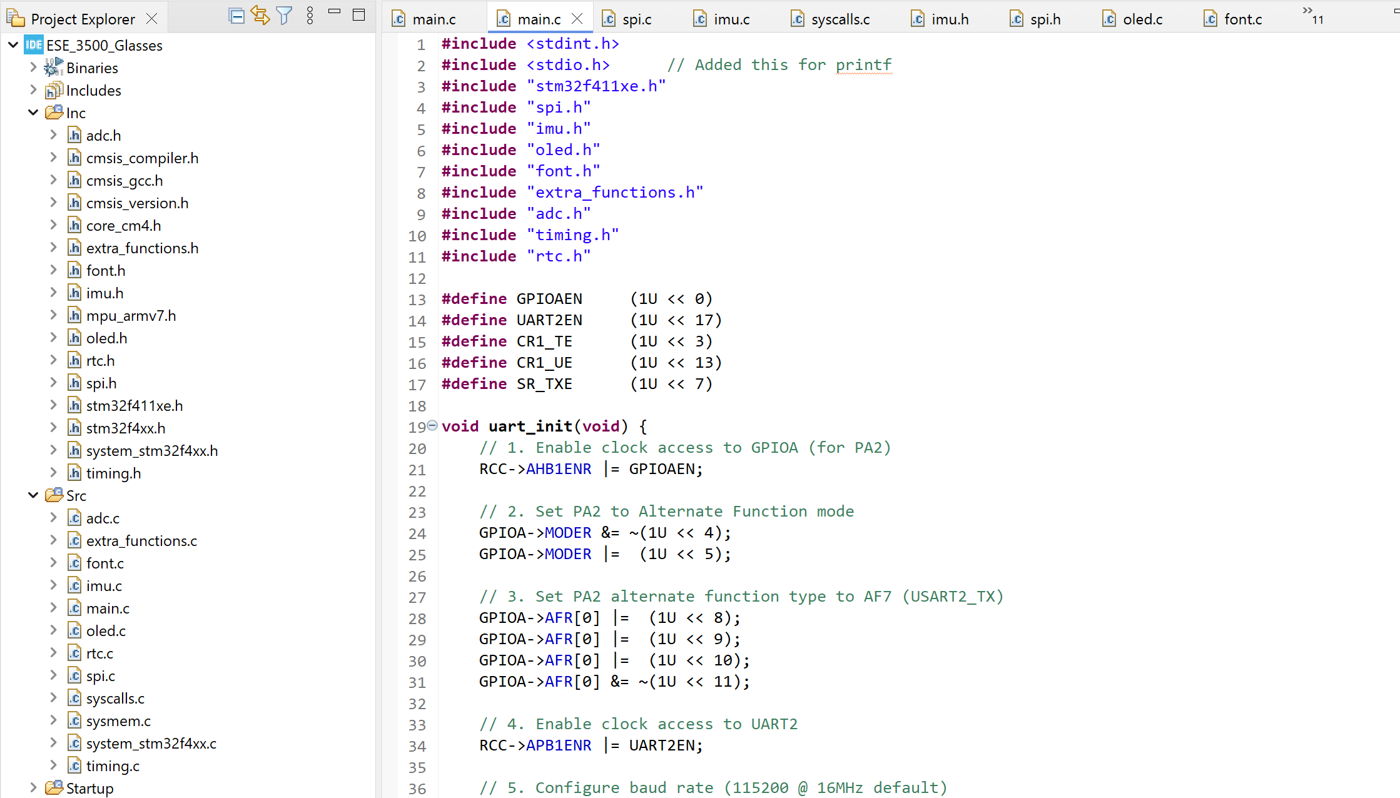
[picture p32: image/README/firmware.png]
Firmware and Drivers


Isometric View:
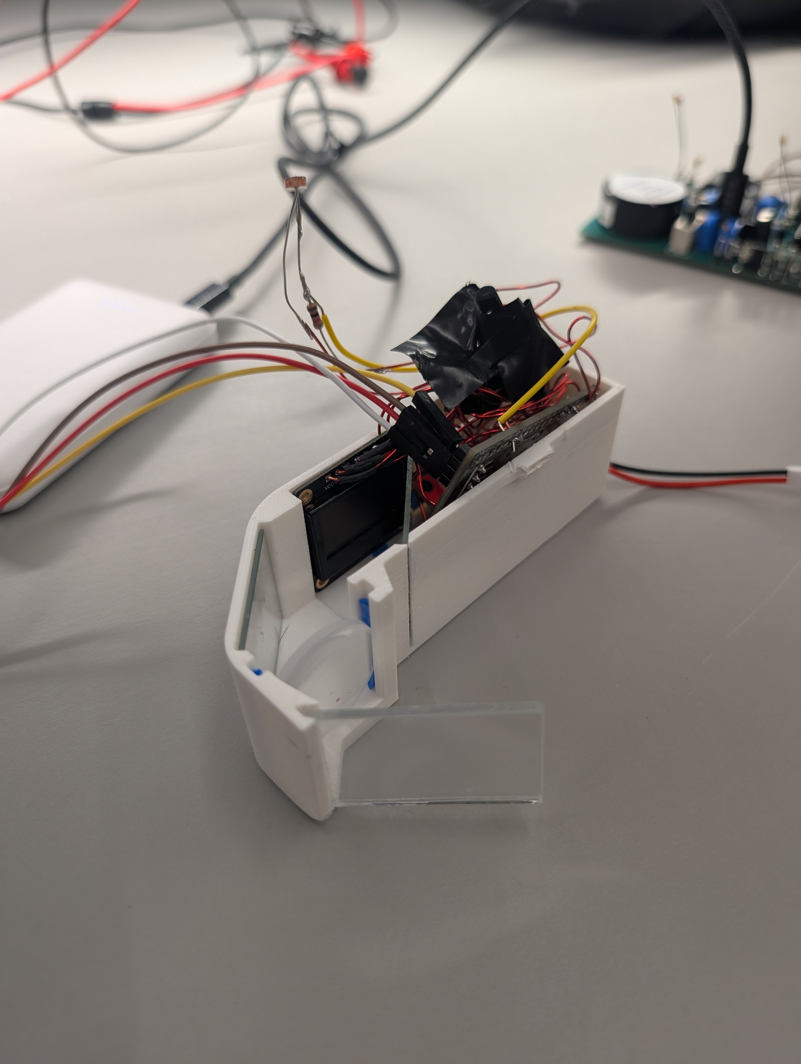
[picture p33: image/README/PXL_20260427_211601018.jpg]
Isometric View


Side View:
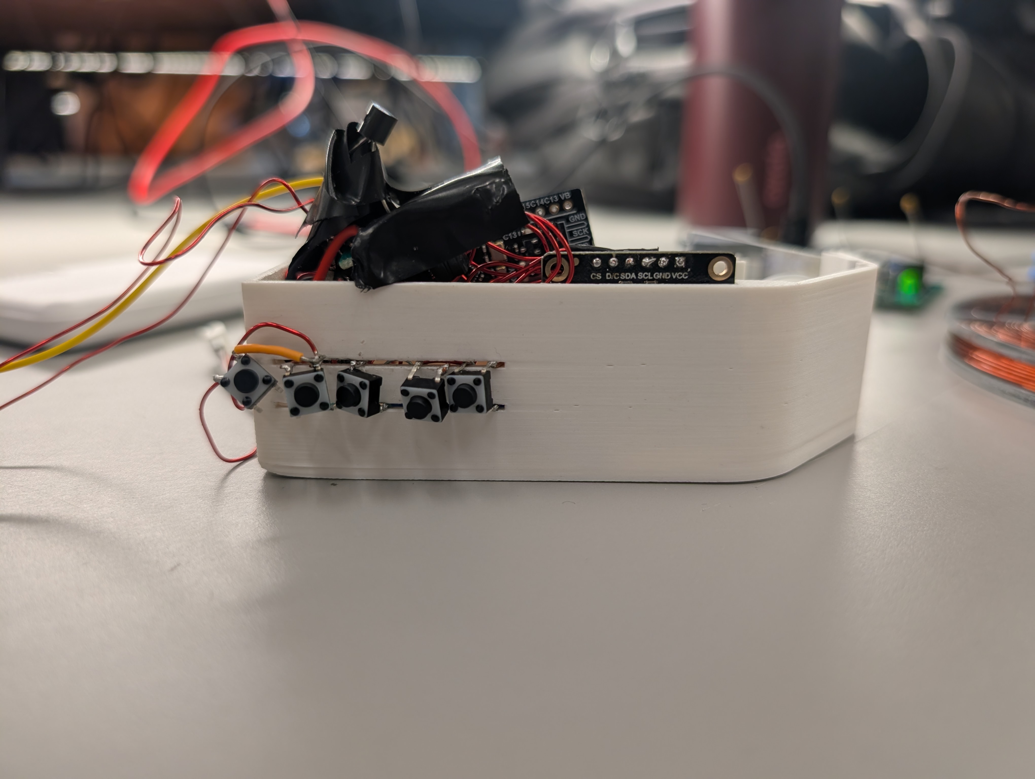
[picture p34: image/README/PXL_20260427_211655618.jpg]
Side View


### 3. Results

Optical System: The optical subsystem was highly successful, creating a visible and clear projection of the OLED in the user's view. The text on the OLED was reflected by two mirrors and directed through a convex lens, hitting a beamsplitter that brought half the light into the user's eye. A virtual image was created 256mm in front, overlaid on the rest of the field of view to create the augmented reality effect. The final measurements and constraints for the optical system are: A convex lens with a diameter of 25mm and a focal point of 71mm. Two first-surface reflecting mirrors, each with a length of 35mm and a height of 15mm. A 50/50 beamsplitter with a length of 50mm and heigh of 30mm. The mirrors were placed at 45 degrees relative to the OLED, and parellel to ensure consistent distances traveled by light across the length of the mirror. The center of the first mirror is 11mm from the screen, and the distance between the two centers of the mirrors were 34mm. The distance from the center of the second mirror iss 11mm from the lens. This creates a total distance of 56mm, being less than the 71mm focal point in order to create a virtual image at -265mm and with a magnification of 4.73. One major change took place during the design of the optical system. A change from a focal point of 32mm to 71mm was required in order to enable a virtual image distance greater than 250mm, the minimum to create a clear image for the human eye. By using optical simulation software, the team was able to design and implment the optical system confidently.

Mechanical System: This system includes the enclousure and lid that houses the optical and hardware systems. This was designed in Fusion 360, with some subsystems designed in Onshape for optimization testing. The enclosure was able to fit all of the hardware including the STM32, OLED, IMU, and buttons. Due to difficulty soldering, not all component ended up being placed inside the enclosure. However, with thinner, more flexible wires, parts would comfortably fit inside as measurement were validated with calipers and assembled with CAD. The optical distances were accurately reflected in the CAD design, which enabled a clear image to be seen on the first attempt.

Hardware & Firmware System: The hardware in the final product includes an STM32F411CEU6 (STM32 Black Pill) for its small form factor. One of the five SPI peripherals, specifically SPI4, is used to communicate and display information on the DFR0934 OLED, which served as our main output device. The glasses had two main input devices. The first, using the SPI2 peripheral, is the LSM6DS0 IMU that records the step count. The second, using an ADC, is a photoresistor divider that captures the ambient light intensity, which allows the system to automatically adjust OLED brightness. Using the step count, the speed is also approximated (in MPH) and displayed onto the OLED screen. To interface with the smart glasses, four buttons are used to trigger external interrupts via GPIO pins. Finally, to power the glasses, a 1s Lipo battery was stepped down to 3.3V using the MCP1700 LDO, which had a typical dropout of 178mV.

To keep the firmware organized, the drivers and code for the SPI peripherals, OLED, ADC, etc. were managed in different files. The main.c file then connects these different files to manage the main GUI. The GUI consisted of 5 distinct screens that the user could cycle through: the welcome screen, time screen, step-count screen, countdown timer screen, and brightness control screen. The welcome screen displays a welcome message. The time screen displays the time, which is calibrated by an external computer upon flashing the code. The step-count screen displays both the speed (in MPH) and step count. The timer screen has a timer which can be adjusted with minute-level precision. Finally, the brightness control screen has 4 brightnesses: low, medium, high, and automatic. Automatic brightness control utilizes the photoresistor and ADC to adjust the brightness.

#### 3.1 Software Requirements Specification (SRS) Results

| ID | Description | Validation Outcome |
| --- | --- | --- |
| SRS-01 | The STM32 shall read the IMU accelerometer data over I2C or SPI at a minimum rate of 50 Hz to enable accurate step detection. | Partially Achieved. The LSM6DS0 6-axis IMU's step data was accurately measured over SPI. However, while desoldering/re-soldering the STM32 to fit the tight space of the glasses enclosure, the SPI peripheral for the IMU was broken for the final product. |
| SRS-02 | The step detection algorithm shall detect a walking step within 400ms of it occurring, with no more than 10% error over a 20-step walk test. | Partially Achieved. The LSM6DS0 6-axis IMU's step data was accurately updated within 400ms of taking a step during testing.. However, while desoldering/re-soldering the STM32 to fit the tight space of the glasses enclosure, the SPI peripheral for the IMU was broken for the final product. |
| SRS-03 | The display shall update its shown content within 500ms of a button press (full round-trip: glasses ESP32 → base ESP32 → STM32 → base ESP32 → glasses ESP32 → display). | Not Relevant. The ESP32 was not used due to excessive power consumption. Decided by the first sprint review. |
| SRS-04 | The STM32 shall synchronize its RTC with NTP time via the base ESP32 over UART once at startup. | Achieved. Although the ESP32 was not used, the RTC fully worked by calibrating it with the time of the computer that flashed the code during compilation. |
| SRS-05 | The display shall cycle through at least three different modes, such as: time view, step count view, and compass view. | Achieved. The glasses had 5 different screens it could cycle through. This is **validated** from the demo video. A brief demo of this is shown in SRS05-Validation.mp4 in the github. ![SRS05-Validation][SRS05-Validation.mp4] (embedded in the actual website) |
| SRS-06 | The STM32 shall receive and process data from the base ESP32 over UART within 100ms of transmission. | Not Relevant. The ESP32 is not used. |
| SRS-07 | The STM32 shall compute the compass direction from the magnetometer data and display cardinal direction (N, NE, E, SE, S, SW, W, NW) accurate to within ±22.5 degrees after calibration. | Not Relevant. A Magnetometer was not used in the final product. |
| SRS-08 | The OLED display will communicate using SPI translated through UART wirelessly between the two ESP32S3 modules to maximize screen data bandwidth. | Achieved. Although the ESP32 was not used, the OLED successfully displayed the output via SPI as **validated** in the demo video. |

#### 3.2 Hardware Requirements Specification (HRS) Results

| ID | Description | Validation Outcome |
| --- | --- | --- |
| HRS-01 | The system shall use an IMU with at least 3-axis accelerometer, 3-axis gyroscope, and 3-axis magnetometer capabilities, communicating over I2C, for step-count and compass data. | Partially Achieved. Instead of a 9-axis IMU, a 6-axis IMU successfully worked using SPI. |
| HRS-02 | The display shall be small enough to mount on glasses frames and support at least two lines of text output. | Achieved. More than two lines of text output was supported and the display was small enough to mount on glasses frames as **validated** in the demo video. |
| HRS-03 | Several push buttons shall be mounted on the glasses frame and register a press within 100ms of actuation to enable mode toggling, parameter changes, and power on/off. | Partially achieved. The buttons are responsive as per the demo video. However, there's a 300ms hardcoded delay to prevent debouncing. |
| HRS-04 | Two ESP32 modules shall maintain wireless connection with a round-trip latency of less than 500ms within 5m of distance. | Not relevant. ESP32 not used. |
| HRS-05 | The STM32 shall communicate with the base ESP32 over UART at a baud rate of at least 9600 bps. | Not relevant. ESP32 not used. |
| HRS-06 | The glasses shall be powered by a battery capable of powering the glasses for at least 15–30 minutes continuously. | Achieved.**Validated** by the specs of the system. STM32 draws ~45mA, OLED ~15mA, IMU ~5mA, Photoresistor ~3mA. <br />These are the upper current-draw values from the datasheets. Additionally, the photoresistor is in series with a 1k ohm resistor, so it has an absolute max draw of 3.3V/1000 = 3.3mA.<br />The LP552530 1s Lipo Battery has 350mAh capacity. <br />With a max total current draw of ~70mA, **350mAh/70mA = 5 hours. This is signficantly above the HRS of 30 minutes even assuming worst-case.** |

### 4. Conclusion

Argus successfully demonstrated a functional pair of bare-metal smart glasses built around the STM32F411CEU. Overall, this project was successful as the most important features were completed and demonstrated. The optics and OLED screen, which are the most important features of the project, worked well as shown in the demo video. The virtual image of the OLED display was successfully projected and could be comfortably seen ~10 inches in front of the user's eye. Additionally, the Real-time clock (RTC) and timer also worked accurately as shown in the demo video. There were, however, some challenges/setbacks primarily due to the compact form-factor of the product. To get the IMU, MCU, LDO, OLED screen, and wires to fit inside the enclosure, the header pins we originally prototyped with had to be desoldered. In doing so, too much heat was applied to some pins, resulting in one of the GPIO pins breaking and some of the SPI peripherals also breaking. The OLED's SPI peripheral was still fully functional, however, one of the buttons was not functional, which is why another button was soldered onto another GPIO pin. Additionally, the SPI peripheral communicating with the IMU broke, meaning that the step-count feature was broken on the final product. Despite these setbacks, the IMU worked during initial testing which shows that if another blackpill STM32 was ordered in time, the step counter would've worked. All other features functioned well.

From this experience, we learned that building a prototype involves not only just prototyping, but also integrating the final product. Ultimately, this is where we struggled the most to turn design and MVP into functional product. Working with the large Nucleo board was much easier than a STM32 Black Pill with many pins missing functionality. In the future, we would be more deliberate in choosing and assembling parts. Several of the first IMUs chosen simply could not work due to issues between STM32 and those specific I2C peripherals, and even prototyping would have been more deliberate (mostly not soldering in those jumper pins because removing those broke our board). Additionally, we would have bought at least one more board for redundancy. As a next step, we really wanted to pursue more navigational features. We think that Argus could have great application as a tool to notify you in situations where you should keep your attention ahead of yourself, so integration with maps or a compass with more intensive bio-tracking could turn this into a much more functional product.

## References

I. Gbati,  *Bare-Metal Embedded C Programming: Develop High-Performance Embedded Systems with C for Arm Microcontrollers* . Birmingham, UK: Packt Publishing, 2024.

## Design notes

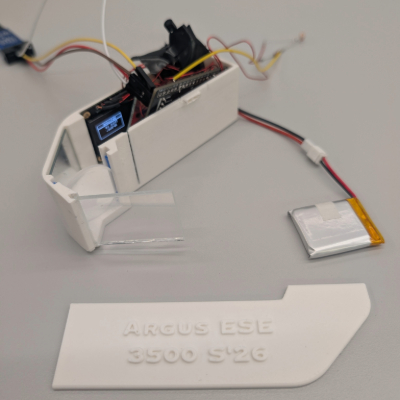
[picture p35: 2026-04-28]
image/README/argus_thumbnail_400x400.jpg

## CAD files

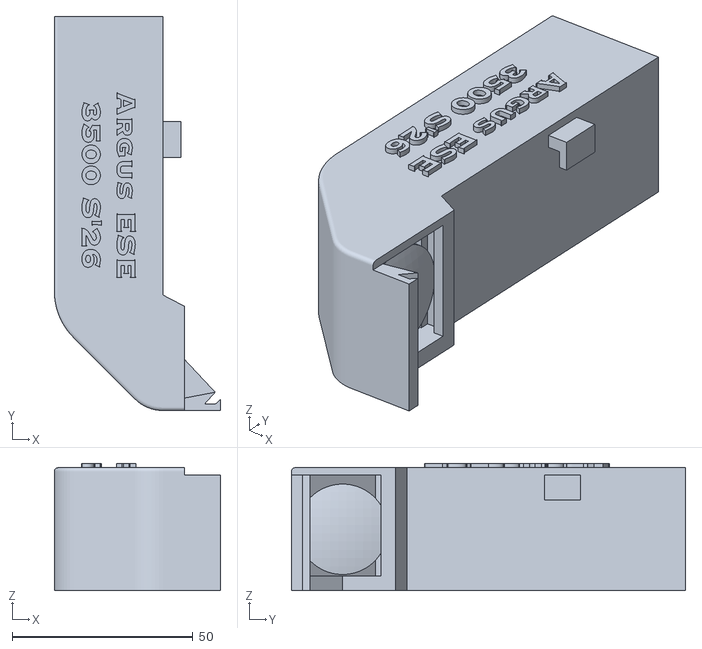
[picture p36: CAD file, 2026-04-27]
Glasses Final ALL copy.stl
46.0 x 108.9 x 35.2

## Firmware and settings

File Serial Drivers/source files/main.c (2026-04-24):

#include <stdint.h>
#include <stdio.h>
#include "stm32f411xe.h"
#include "spi.h"
#include "imu.h"
#include "oled.h"
#include "font.h"
#include "extra_functions.h"
#include "adc.h"
#include "timing.h"
#include "rtc.h"

#define GPIOAEN     (1U << 0)
#define UART2EN     (1U << 17)
#define CR1_TE      (1U << 3)
#define CR1_UE      (1U << 13)
#define SR_TXE      (1U << 7)



// Screen state — volatile because ISR modifies it
volatile uint8_t current_screen = 0; // state of screen
volatile uint8_t screen_changed = 1;  // start with 1 to draw initial screen
#define NUM_SCREENS 5


// timer variable
volatile uint32_t timer_seconds = 60;
volatile uint32_t timer_running = 0;
volatile uint32_t last_tick = 0;

// brightness of OLED
volatile uint8_t brightness_level = 1; // 0=Low, 1=Medium, 2=High, 3 = auto
/*
 *  INTERRUPTS
 */

// PB1 pressed. Handles screen changes
void EXTI1_IRQHandler(void) {

	static uint32_t last_press = 0; // lives in .data for lifetime of program

	if ((get_tick() - last_press) > 300) { // prevent debouncing
		if (!(GPIOB->IDR & (1U << 1))) {
			if (!timer_running){
				last_press = get_tick();
				current_screen = (current_screen + 1) % NUM_SCREENS;
				screen_changed = 1;
			}
		}
	}

	EXTI->PR = (1U << 1); // write 1 to clear flag otherwise NVIC will keep reentering interrupt handler

}


// PB2 pressed. Handles starting/stopping the timer.
void EXTI2_IRQHandler(void) {
	 if (EXTI->PR & (1U << 2)) {
	        EXTI->PR |= (1U << 2);
	        if (timer_seconds > 0) {
	            timer_running ^= 1;
	            last_tick = get_tick();
	            if (current_screen == 3) {
	            	screen_changed = 1;
	            }
	        }
	    }
}

// PB3 pressed. Increments timer
void EXTI3_IRQHandler(void) {
	 if (EXTI->PR & (1U << 3)) {
	        EXTI->PR |= (1U << 3);
	        if (!timer_running && timer_seconds < 3599 && current_screen == 3) {
	            if (timer_seconds >= 3539) timer_seconds = 3599;
	            else timer_seconds += 60;
	            if (current_screen == 3) screen_changed = 1;
	        }
	        if (current_screen == 4) {
	        	if (brightness_level < 3) brightness_level++;
	        	else brightness_level = 0;
				screen_changed = 1;
	        }
	 }
}

// PB4 pressed. Decrements timer
void EXTI4_IRQHandler(void) {
    if (EXTI->PR & (1U << 4)) {
        EXTI->PR |= (1U << 4);
        if (!timer_running && timer_seconds > 0 && current_screen == 3) {
            if (timer_seconds <= 59) timer_seconds = 0;
            else timer_seconds -= 60;
            if (current_screen == 3) screen_changed = 1;
        }
    }
}




// Timer 2 interrupt every 100ms
static int second_calibration = 0;
void TIM2_IRQHandler(void) {

    if (TIM2->SR & (1 << 0)) { // check if flag is set
        TIM2->SR &= ~(1 << 0); // clear flag

        // Update brightness auto
        if (brightness_level == 3) oled_brightness(adc_read());

        // Update Time
        second_calibration += 1;
        if (second_calibration == 9){
        	second_calibration = 0;
        	if (current_screen == 1){
				screen_changed = 1;
			}
        }
    }
}

// calibrate time from compilation time
static void set_time_from_compile(void) {
    // __TIME__ is a string literal: "HH:MM:SS"
    uint8_t h = (__TIME__[0] - '0') * 10 + (__TIME__[1] - '0');
    uint8_t m = (__TIME__[3] - '0') * 10 + (__TIME__[4] - '0');
    uint8_t s = (__TIME__[6] - '0') * 10 + (__TIME__[7] - '0');
    rtc_set_time(h, m, s);
}


// Defining visible are of OLED
// 6 pixels per character
#define VIS_X    45 // X coordinate of the left edge (ends up being flipped horizontally, making it the right edge)
#define VIS_Y    10 // y coordinate of the top edge
#define VIS_W    80 // width of rectangles
#define VIS_H    44 // total height of both rectangles combined
#define TOP_H    (VIS_H / 4)        // 11px - height of top rectangle
#define BOT_H    (VIS_H - TOP_H)    // 33px - height of bottom rectangle
#define VIS_MID_Y (VIS_Y + TOP_H) // y coordinate of the top edge of bottom rectangle

// FOR BOTTOM RECTANGLE: we get 3 lines of text
// VIS_MID_Y + 3
// VIS_MID_Y + 13
// VIS_MID_Y + 23


int main(void)
{
	delay_init(); // start counting ticks
    spi1_init(); // SPI1 for IMU communication
    setup_GPIO(); // GPIO setup
    spi4_init(); // SPI4 for OLED
    oled_init(); // OLED
    exti_init(); // Initialize IMU interrupt on STM
    adc_init(); // ADC
    imu_enable_step_interrupt(); // IMU interrupt enable
    TIM2_init(); // timer2 for interrupts
    rtc_init(); // RTC for the time
    set_time_from_compile();

    if (imu_init() == 0) {
        // If IMU fails, halt
        //while(1);
    }

    char buf[12]; // for step count
    char spd_buf[12] = "0.0 MPH";




    while (1) {

    	if (timer_running && (get_tick() - last_tick >= 1000)) {
    	    __disable_irq();
    	    last_tick += 1000;
    	    timer_seconds--;
    	    if (current_screen == 3) screen_changed = 1;
    	    if (timer_seconds == 0) timer_running = 0;
    	    __enable_irq();
    	}

    	// auto-update screen when step count updates
    	if (step_flag) {
    		step_flag = 0;

    		if (current_screen == 2) {
    			calculate_speed_from_steps(spd_buf, sizeof(spd_buf));
    			screen_changed = 1;
    		}
    	}

    	// Main screen handler
    	if (screen_changed) {
    		screen_changed = 0;
    		oled_clear();

    		// GUI made from rectangles
    		draw_rect(VIS_X, VIS_Y, VIS_W, TOP_H);   // small header box
    		draw_rect(VIS_X, VIS_MID_Y, VIS_W, BOT_H);   // large content box


    		switch (current_screen) {
    		// MAIN SCREEN
    			case 0:
    				draw_string(64, VIS_Y + 2, "Welcome");
    				draw_string(61, VIS_MID_Y + 3,  "This is");
    				draw_string(67, VIS_MID_Y + 13, "Argus.");
					break;

    		// TIME
    			case 1:
    				uint8_t h, m, s;
					rtc_get_time(&h, &m, &s);

					const char *period = (h >= 12) ? "PM" : "AM";
					uint8_t h12 = h % 12;
					if (h12 == 0) h12 = 12;

					char time_buf[9];
					time_buf[0] = '0' + h12 / 10;
					time_buf[1] = '0' + h12 % 10;
					time_buf[2] = ':';
					time_buf[3] = '0' + m / 10;
					time_buf[4] = '0' + m % 10;
					time_buf[5] = ':';
					time_buf[6] = '0' + s / 10;
					time_buf[7] = '0' + s % 10;
					time_buf[8] = '\0';

					draw_string(73, VIS_Y + 2,      "TIME");
					draw_string(61, VIS_MID_Y + 3,  time_buf);
					draw_string(79, VIS_MID_Y + 13, period);
					break;
			// STEPS
    			case 2:
    				draw_string(70, VIS_Y + 2,      "STEPS");
    				uint_to_str(read_steps(), buf);
    				draw_string(73, VIS_MID_Y + 3,  buf);
    				draw_string(61, VIS_MID_Y + 13, spd_buf);
					break;
			// TIMER
    			case 3:
    				char tbuf[6];
					uint32_t timer_minute = timer_seconds / 60;
					uint32_t timer_second = timer_seconds % 60;
					tbuf[0] = '0' + timer_minute / 10; tbuf[1] = '0' + timer_minute % 10;
					tbuf[2] = ':';
					tbuf[3] = '0' + timer_second / 10; tbuf[4] = '0' + timer_second % 10;
					tbuf[5] = '\0';
					draw_string(70, VIS_Y + 2,      "TIMER");
					draw_string(70, VIS_MID_Y + 3,  tbuf);
					draw_string(64, VIS_MID_Y + 13, timer_running ? "RUNNING" : "STOPPED");
					break;

			// BRIGHTNESS CONTROL
    			case 4:
					draw_string(55, VIS_Y + 2, "BRIGHTNESS");

					const uint8_t levels[3] = {50, 150, 255};
					if (brightness_level < 3) oled_brightness(levels[brightness_level]);

					// all the brightness types - 4 types: low, medium, high, auto
					draw_string(VIS_X + 4, VIS_MID_Y + 3,  brightness_level == 0 ? ">Low"    : " Low");
					draw_string(VIS_X + 4, VIS_MID_Y + 13, brightness_level == 1 ? ">Medium" : " Medium");
					draw_string(VIS_X + 4, VIS_MID_Y + 23, brightness_level == 2 ? ">High"   : " High");
					// IF none of the options are selected, it means auto.
					break;
    		}
    	}
    }
}

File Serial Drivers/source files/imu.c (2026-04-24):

/*
 * imu.c
 *  Created on: 04/03/2026
 *  Author: Jerry Zhang
 *  Description: SPI driver for LCD display
 *
 */


#include "imu.h"
#include "timing.h"
#include "extra_functions.h"
#include <string.h>
#include <stdio.h>

/**************************************************************************//**
* @fn			uint8_t imu_init(void)
* @brief		Initialize all IMU settings to turn on step counter
* @note
*****************************************************************************/
uint8_t imu_init(void) {
    if (imu_read(IMU_WHO_AM_I) != IMU_ID) return 0; // verify device ID

    imu_write(IMU_CTRL1_XL, IMU_ODR | IMU_FS); // set accelerometer performance settings
    imu_write(IMU_CTRL10_C, IMU_TIMESTAMP_EN); // enable time stamp for step counter

    imu_write(EMB_FUNC_CFG_ACCESS, FUNC_CFG_ACCESS); // enable access to embedded functions
    imu_write(EMB_FUNC_EN_A, IMU_PEDO_EN); // enable pedometer
    imu_write(EMB_FUNC_CFG_ACCESS, 0x00); // disable access to embedded functions

    return 1;                               // success
}

/**************************************************************************//**
* @fn			void imu_write(uint8_t reg_addr, uint8_t data)
* @brief		Write a byte of data into a register address on the IMU
* @note
*****************************************************************************/
void imu_write(uint8_t reg_addr, uint8_t data) {
    cs1_enable();
    spi1_transfer(reg_addr & ~0x80); // MSB is 0 to Write
    spi1_transfer(data);     // send the data byte
    cs1_disable();
}

/**************************************************************************//**
* @fn			uint8_t imu_read(uint8_t reg_addr)
* @brief		Read the byte at the register address specified
* @note
*****************************************************************************/
uint8_t imu_read(uint8_t reg_addr) {
    uint8_t result;
    cs1_enable();
    spi1_transfer(reg_addr | 0x80); // Set MSB to 1 to read
    result = spi1_transfer(0x00);   // Send dummy byte to receive data
    cs1_disable();
    return result;
}

/**************************************************************************//**
* @fn			void imu_read_multiple(uint8_t reg_addr, uint8_t *buffer, uint32_t size)
* @brief		Read size number of bytes into a buffer starting from register address
* @note
*****************************************************************************/
void imu_read_multiple(uint8_t reg_addr, uint8_t *buffer, uint32_t size) {
    cs1_enable();
    spi1_transfer(reg_addr | 0x80); // Set MSB to 1 to read
    spi1_read(buffer, size);        // Read multiple bytes into buffer
    cs1_disable();
}

/**************************************************************************//**
* @fn			void imu_readxyz(uint8_t reg_addr, uint8_t *buffer)
* @brief		Read 6 bytes of data for x, y, z axis readings
* @note
*****************************************************************************/
void imu_readxyz(uint8_t reg_addr, uint8_t *buffer) {
    imu_read_multiple(reg_addr, buffer, 6); // Read 6 bytes for x, y, z
}


/**************************************************************************//**
* @fn			uint16_t read_steps(void)
* @brief		Read the high and low bits of step counter array, combine them, then return step count
* @note
*****************************************************************************/
uint32_t read_steps(void) {

    for(volatile int i = 0; i < 2000; i++);
    imu_write(EMB_FUNC_CFG_ACCESS, FUNC_CFG_ACCESS); // enable access to embedded functions

    uint8_t step_l = imu_read(STEP_COUNTER_L);
    uint8_t step_h = imu_read(STEP_COUNTER_H);

    imu_write(EMB_FUNC_CFG_ACCESS, 0x00); // disable access to embedded functions
    for(volatile int i = 0; i < 2000; i++);
    return (step_h << 8) | step_l; // return combined bytes
}

/**************************************************************************//**
* @fn			void imu_enable_step_interrupt(void)
* @brief		Set up the interrupt for the step counter to avoid polling
* @note
*****************************************************************************/
void imu_enable_step_interrupt(void) {
    // 1. Enable step counter interrupt from INT1 pin
	imu_write(MD1_CFG, 0x02);
	imu_write(EMB_FUNC_CFG_ACCESS, FUNC_CFG_ACCESS);
	imu_write(EMB_FUNC_INT1, 0x08);
	imu_write(EMB_FUNC_CFG_ACCESS, 0x00);
}

/**************************************************************************//**
* @fn			void exti_init(void)
* @brief		Initialize INT1 interrupt
* @note
*****************************************************************************/
void exti_init(void) {
    RCC->AHB1ENR |= (1U << 0);      // 1. Enable GPIOA clock
    GPIOA->MODER &= ~(3U << 16);    // 2. Set PA8 to Input Mode (bits 16 & 17)

    RCC->APB2ENR |= (1U << 14);     // 3. Enable SYSCFG clock

    // 4. Map EXTI8 to Port A
    // EXTICR[2] handles EXTI8, 9, 10, 11. EXTI8 is at bit position 0.
    SYSCFG->EXTICR[2] &= ~(0xF << 0); // Clear it (Defaults to Port A / 0000)

    EXTI->IMR |= (1U << 8);         // 5. Unmask EXTI Line 8
    EXTI->RTSR |= (1U << 8);        // 6. Trigger on Rising Edge

    NVIC_EnableIRQ(EXTI9_5_IRQn);   // 7. Enable the shared 5-9 NVIC line
}

volatile uint32_t step_count = 0;
volatile uint8_t step_flag = 0;

/**************************************************************************//**
* @fn			void EXTI0_IRQHandler(void)
* @brief		Handles the interrupt from the IMU on PA0
* @note
*****************************************************************************/
/**************************************************************************//**
* @fn			void EXTI9_5_IRQHandler(void)
* @brief		Handles the interrupt from the IMU on PA8
* @note
*****************************************************************************/
void EXTI9_5_IRQHandler(void) {
    // Check if the interrupt specifically came from EXTI Line 8 (PA8)
    if (EXTI->PR & (1U << 8)) {

        // Clear the interrupt flag for Line 8
        EXTI->PR |= (1U << 8);

        step_count++;
        step_flag = 1;
    }
}


static uint32_t last_total_steps = 0;
void calculate_speed_from_steps(char *buffer, int size) {
    // calculate the speed based on the number of steps taken in a certain time frame
    // use that average human walk speed = 2.5ft per step, run is 4.5ft per step
    uint32_t current_total_steps = read_steps();

    // steps in last second
    uint16_t delta_steps = (uint16_t)(current_total_steps - last_total_steps);
    last_total_steps = current_total_steps;

    float stride_length = (delta_steps > 2) ? 4.5f : 2.5f;

    // 3. Calculate Speed (Feet per Second)
    // Since time window is 1 second, Speed = delta_steps * stride
    float speed_fps = (float)delta_steps * stride_length;
    float speed_mph = (speed_fps * 3600) / 5280;

    uint16_t non_decimals = (uint16_t)speed_mph;
    uint16_t decimals = ((uint16_t)(speed_mph * 10)) % 10;
    snprintf(buffer, size, "%d.%d MPH", non_decimals, decimals);
}
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

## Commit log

2026-03-16 finish bom
2026-04-06 finisih spi driver later
2026-04-07 4/7 spi
2026-04-08 barebones spi1 driver complete, ready for implementing imu or oled depending on what uses spi1
2026-04-09 first version of all drivers done, now testing
2026-04-09 revision 2 of imu and spi drivers
2026-04-12 Sprint Review 2: Mechanical design and CAD
2026-04-12 sprint review #2 progress before pulling images of CAD
2026-04-12 oled prototype firmware
2026-04-13 basic screen switching done
2026-04-17 adc added and oled updated
2026-04-19 clock and improvements from timer
2026-04-20 redesign cad, lens optics 71mm
2026-04-23 oled soldered
2026-04-23 oled soldered 2
2026-04-24 imu code update, reset added
    [imu.c]
2026-04-24 imu.h mismatch fixed
2026-04-24 images of print, projection
2026-04-24 Add GitHub Pages website with STL viewer and project documentation
2026-04-25 reverted back to original spi1
    [imu.c, main.c, spi.c]
2026-04-27 results optics and CAD sections
2026-04-27 Update STL viewer to load repo model directly, fix image sizing
    - Load Glasses Final ALL copy.stl automatically (no upload UI)
    - Remove grid, add product-render lighting with auto-rotate
    - Fix all img-card images to use object-fit: contain so nothing is cropped
    [Glasses Final ALL copy.stl]
2026-04-27 Switch 3D viewer from STL to OBJ+MTL with Fusion 360 materials
2026-04-27 Rotate 3D model on Z axis instead of Y
2026-04-27 images into report mech/cad/demo
